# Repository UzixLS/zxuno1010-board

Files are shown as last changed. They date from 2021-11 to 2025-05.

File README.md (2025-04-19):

## ZX-UNO.1010
10x10cm PCB variant of ZX-Uno project

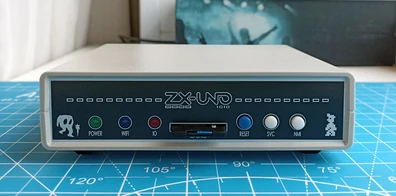
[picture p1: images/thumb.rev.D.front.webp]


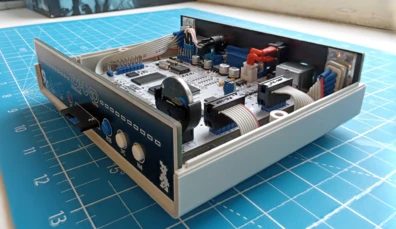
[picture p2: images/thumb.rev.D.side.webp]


[[More photos]](images/README.md)

Tech specs:
- Fully compatible with ZX Uno v4.1 and ZX-Uno VGA 2M
- XC6SLX9 FPGA
- 2Mb SRAM memory
- VGA video output
- PAL/NTSC video + audio output via 3.5 jack connector (raspberry-pi compatible pinout)
- PS/2 keyboard and mouse ports
- 2xDB-9 ports for Atari-compatible joysticks
- SD/microSD card slot
- Tape input via Bluetooth module or ordinary 3.5 jack
- MIDI
- WiFi module
- RTC (starting from rev.B)
- Type C (starting from rev.D) or MicroUSB power supply
- Board optimized for G738 and G706 cases

FAQ on official site: [link](https://uto.speccy.org/zxunofaq_en.html)

Some random photos: [link](https://cloud.err200.net/index.php/s/73TR85tYZkMm8Ax?path=%2Fzxuno1010)

### Changelog
* Rev.A - first release ([main pcb errata](pcb/rev.A/ERRATA.txt) and [covers errata](pcb_covers/rev.A/ERRATA.txt)).
* Rev.A1 - fixes all known issues of rev.A.
* Rev.B:
    * added RTC
    * changed second joystick port wiring - in rev.A it's has been wired like in ZXUNO-VGA2M, but now it's wired like Joysplitter, which is officially supported way
    * joysticks are now powered by +5V rail instead of +3.3V - this should improve compatibility with various RF gamepads
    * optimized SAM2695 footprint for hand soldering
    * added opamp for proper MIDI sound mixing
    * added buffer in DAC circuit
    * added separate LDO for SD card and WiFi module
    * added resistor between WiFi's GPIO15 and GND to prevent IC heating
    * remove beeper (which wasn't used anyway)
    * improved power distribution for FPGA chip
    * pcb corners are rounded now
    * experimental tape-in circuit
* Rev.C:
    * added dedicated LDO for audio to improve noise floor
    * added optional capacitor for NTSC quartz stability
    * added missing decoupling capacitor on RTC power rail
    * added current-limiting resistors after opamp on sound output
    * changed R76, R80 from 10kΩ to 8.2kΩ
    * changed U10 opamp from NE5532 to LMV358 as it better suited for low-voltage operation
    * 3mm front leds replaced by 5mm
    * experimental reset circuit based on MAX809
    * reverted to old tape-in circuit
* Rev.D:
    * used USB Type C instead of Micro USB
    * PJ-320 3.5mm jack replaced by PJ-322
    * added solder jumper to select 3.5mm jack CVBS pinout
    * MIDI synthesizer U6 uses clean analog power rail now
    * improved W25Q128 footprint to able to install IC in WSON package
    * some minor PCB layout changes to reduce WiFi interference
    * reverted to old reset circuit
* Rev.D1:
    * changed R16 from 220Ω to 1kΩ to reduce power led bightness
    * changed R70, R71 from 10kΩ to 12kΩ to improve balance with AY
    * changed C51 from 100nF to 1uF to improve audio noise floor
    * changed C13 value as some quartz failed to start with 4.3pF load
    * changed U17 from LP2985-3.3 to TPS7A2033PDBVR due to better PSRR
    * changed U15 from 74LVC2G34 to 74LVC2G04 as it's more common in my projects

### References
* ZX Uno official site: [link](https://zxuno.speccy.org/index_e.shtml)
* ZX Uno VGA 2M: [link](https://github.com/ManuFerHi/ZXUNO_VGA_2M)
* Great collection of cores, games and much stuff for ZX Uno: [link](https://www.zxuno.com/forum/viewtopic.php?f=27&t=4142), [in english](https://www-zxuno-com.translate.goog/forum/viewtopic.php?f=27&t=4142&_x_tr_sl=es&_x_tr_tl=en)

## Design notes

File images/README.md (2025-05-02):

# Gallery

## Revision D

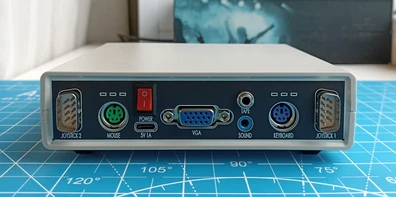
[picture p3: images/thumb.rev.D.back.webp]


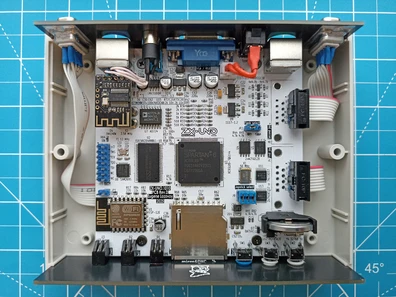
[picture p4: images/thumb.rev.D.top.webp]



## Revision C
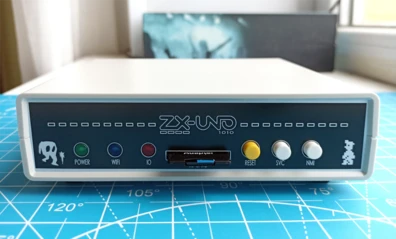
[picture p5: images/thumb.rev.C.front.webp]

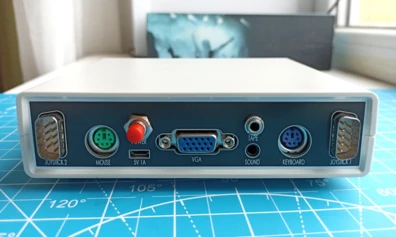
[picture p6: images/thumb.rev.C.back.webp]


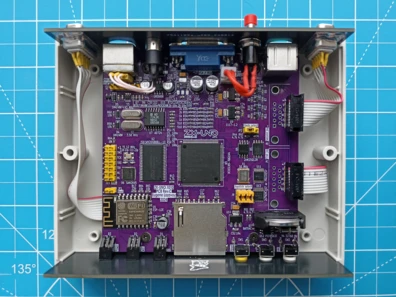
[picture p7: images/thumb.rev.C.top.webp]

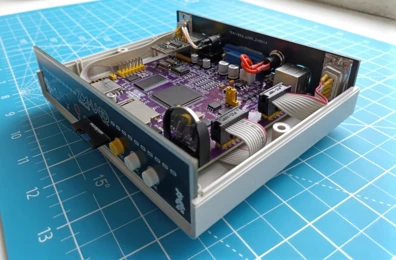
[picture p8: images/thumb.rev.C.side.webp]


## Revision A
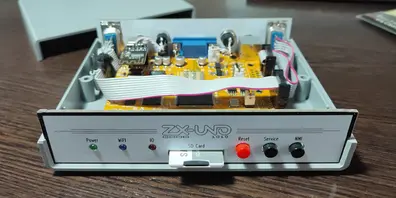
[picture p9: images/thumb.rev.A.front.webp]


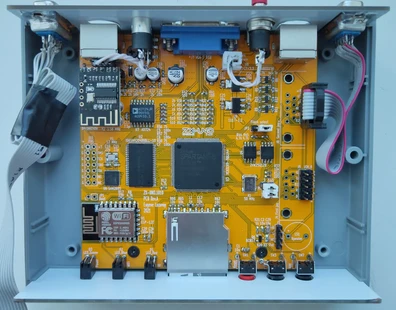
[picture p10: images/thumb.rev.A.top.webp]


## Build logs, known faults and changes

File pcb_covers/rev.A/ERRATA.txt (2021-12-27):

1. All holes should be 0.5mm lower;
2. PS/2 holes should have 6.3mm radius.

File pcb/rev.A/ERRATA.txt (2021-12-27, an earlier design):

1. R8 = 0 ohm;
2. C13 = 4.3pF;
3. D1 led behaviour is inverted (led off when SD is active).

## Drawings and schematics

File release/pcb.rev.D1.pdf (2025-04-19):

1 | 2 | 3 | 4 | 5 | 6 | 7 | 8 | 9 | 10

A

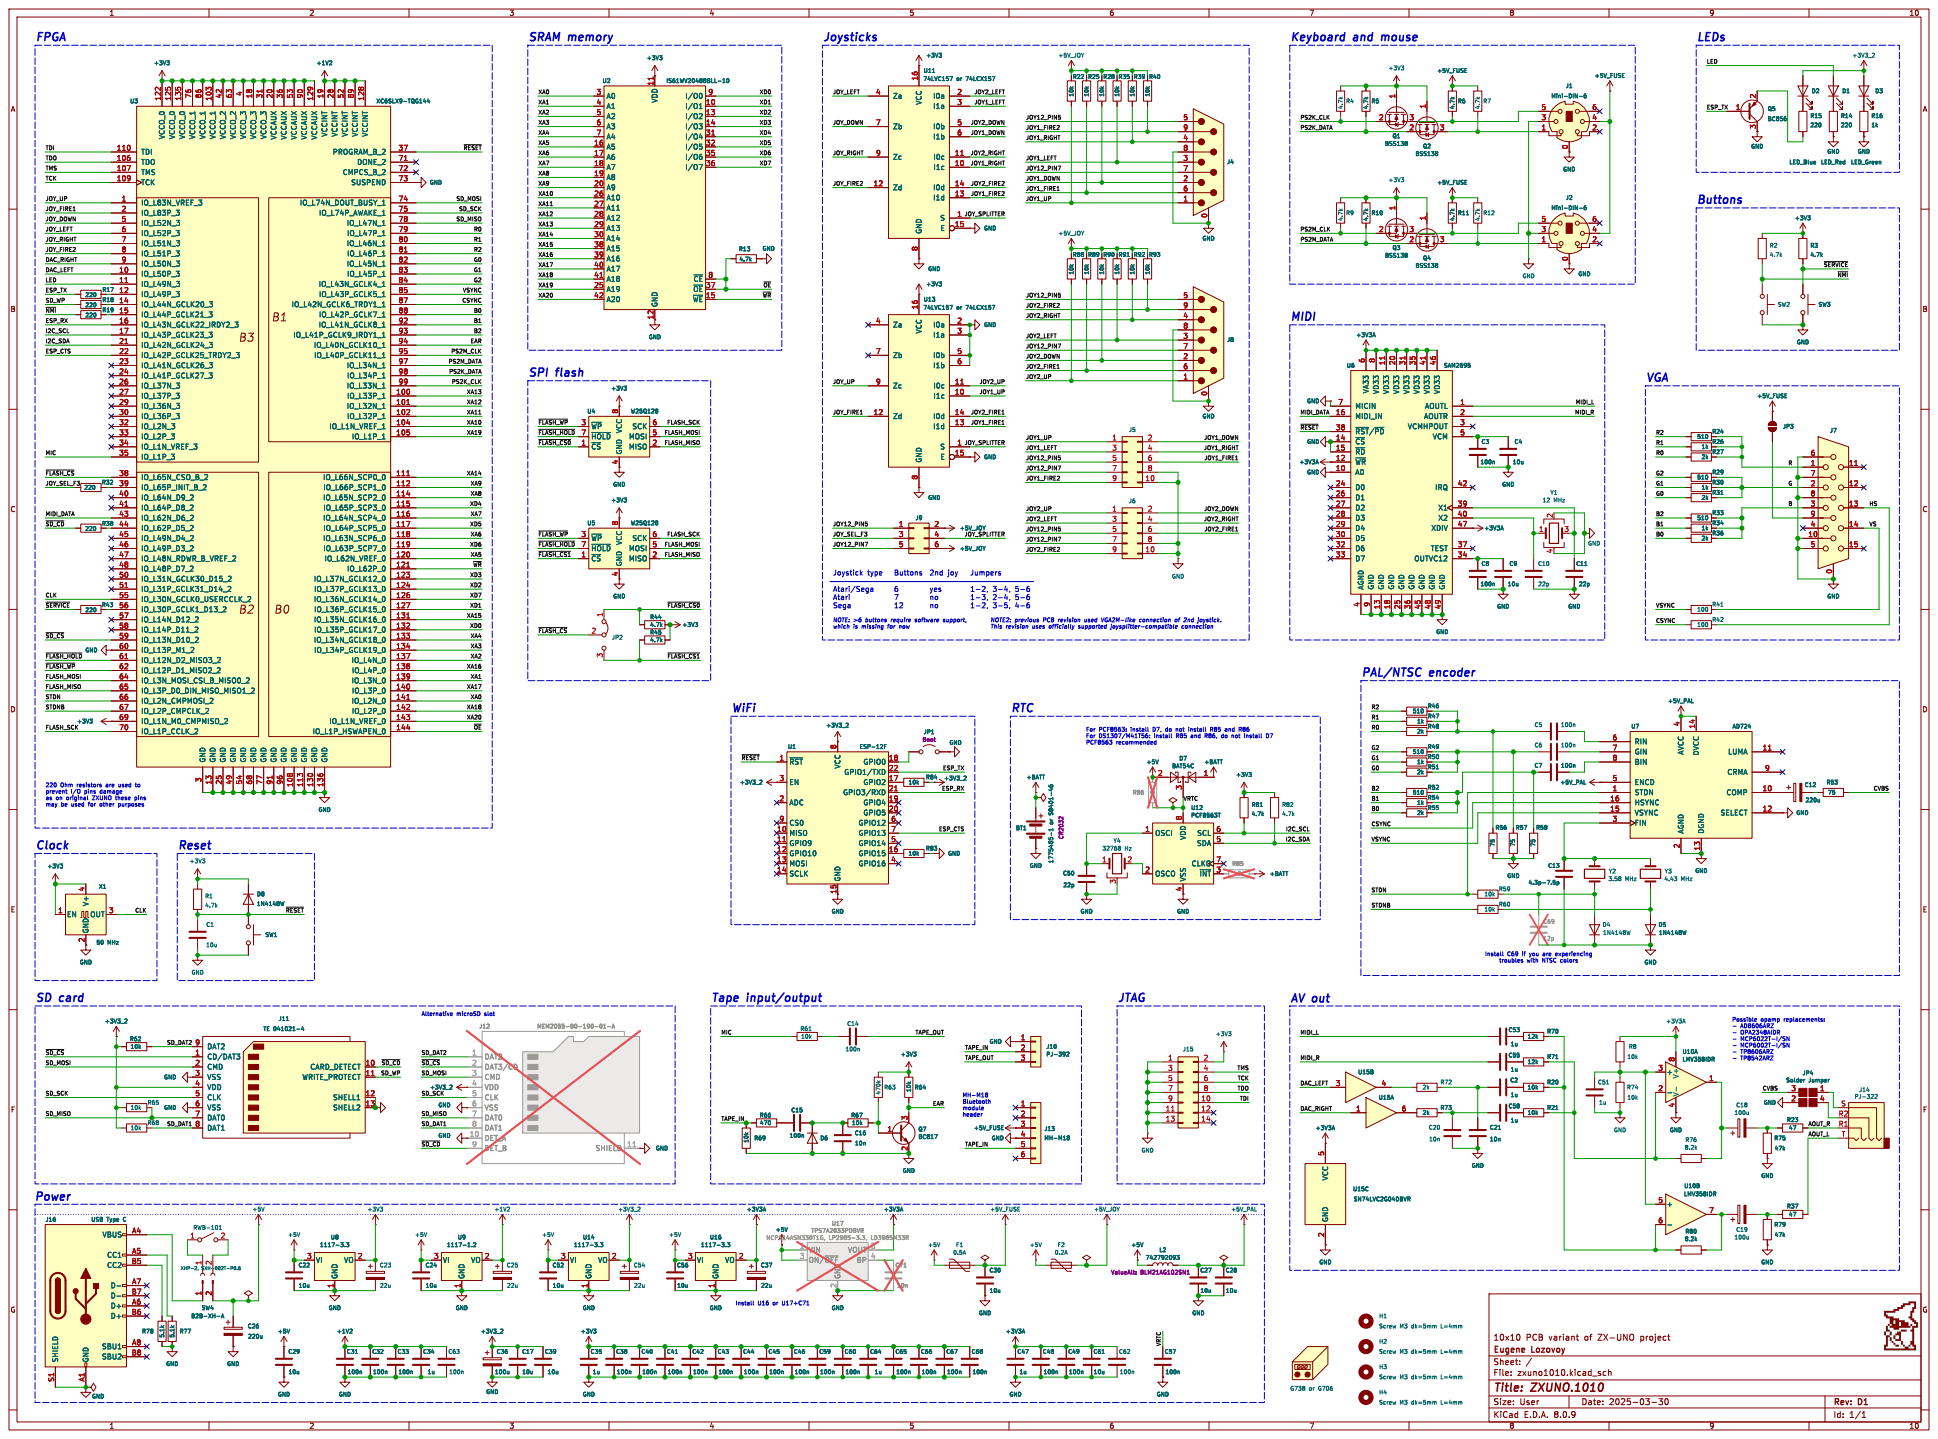
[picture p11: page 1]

4 MOSI 5 SCK 6 ~{HOLD} 7 VCC

Joystick type Atari/Sega Atari Sega

PAL/NTSC encoder MH-M18 Bluetooth module
B1G2 G1 R0 DAC_LEFT DAC_RIGHT MIDI_R

12 DGND 13 DVCC ¹⁴ VSYNC

4 SDA 5 SCL 6 CLKO 7 VDD

2 ON/~{OFF} 3 BP 4 VOUT 5 U17 TPS7A2033PDBVR

2 ON/~{OFF} 3 BP 4 VOUT 5 C65

1 | 2 | 3 | 4 | 5 | 6

A

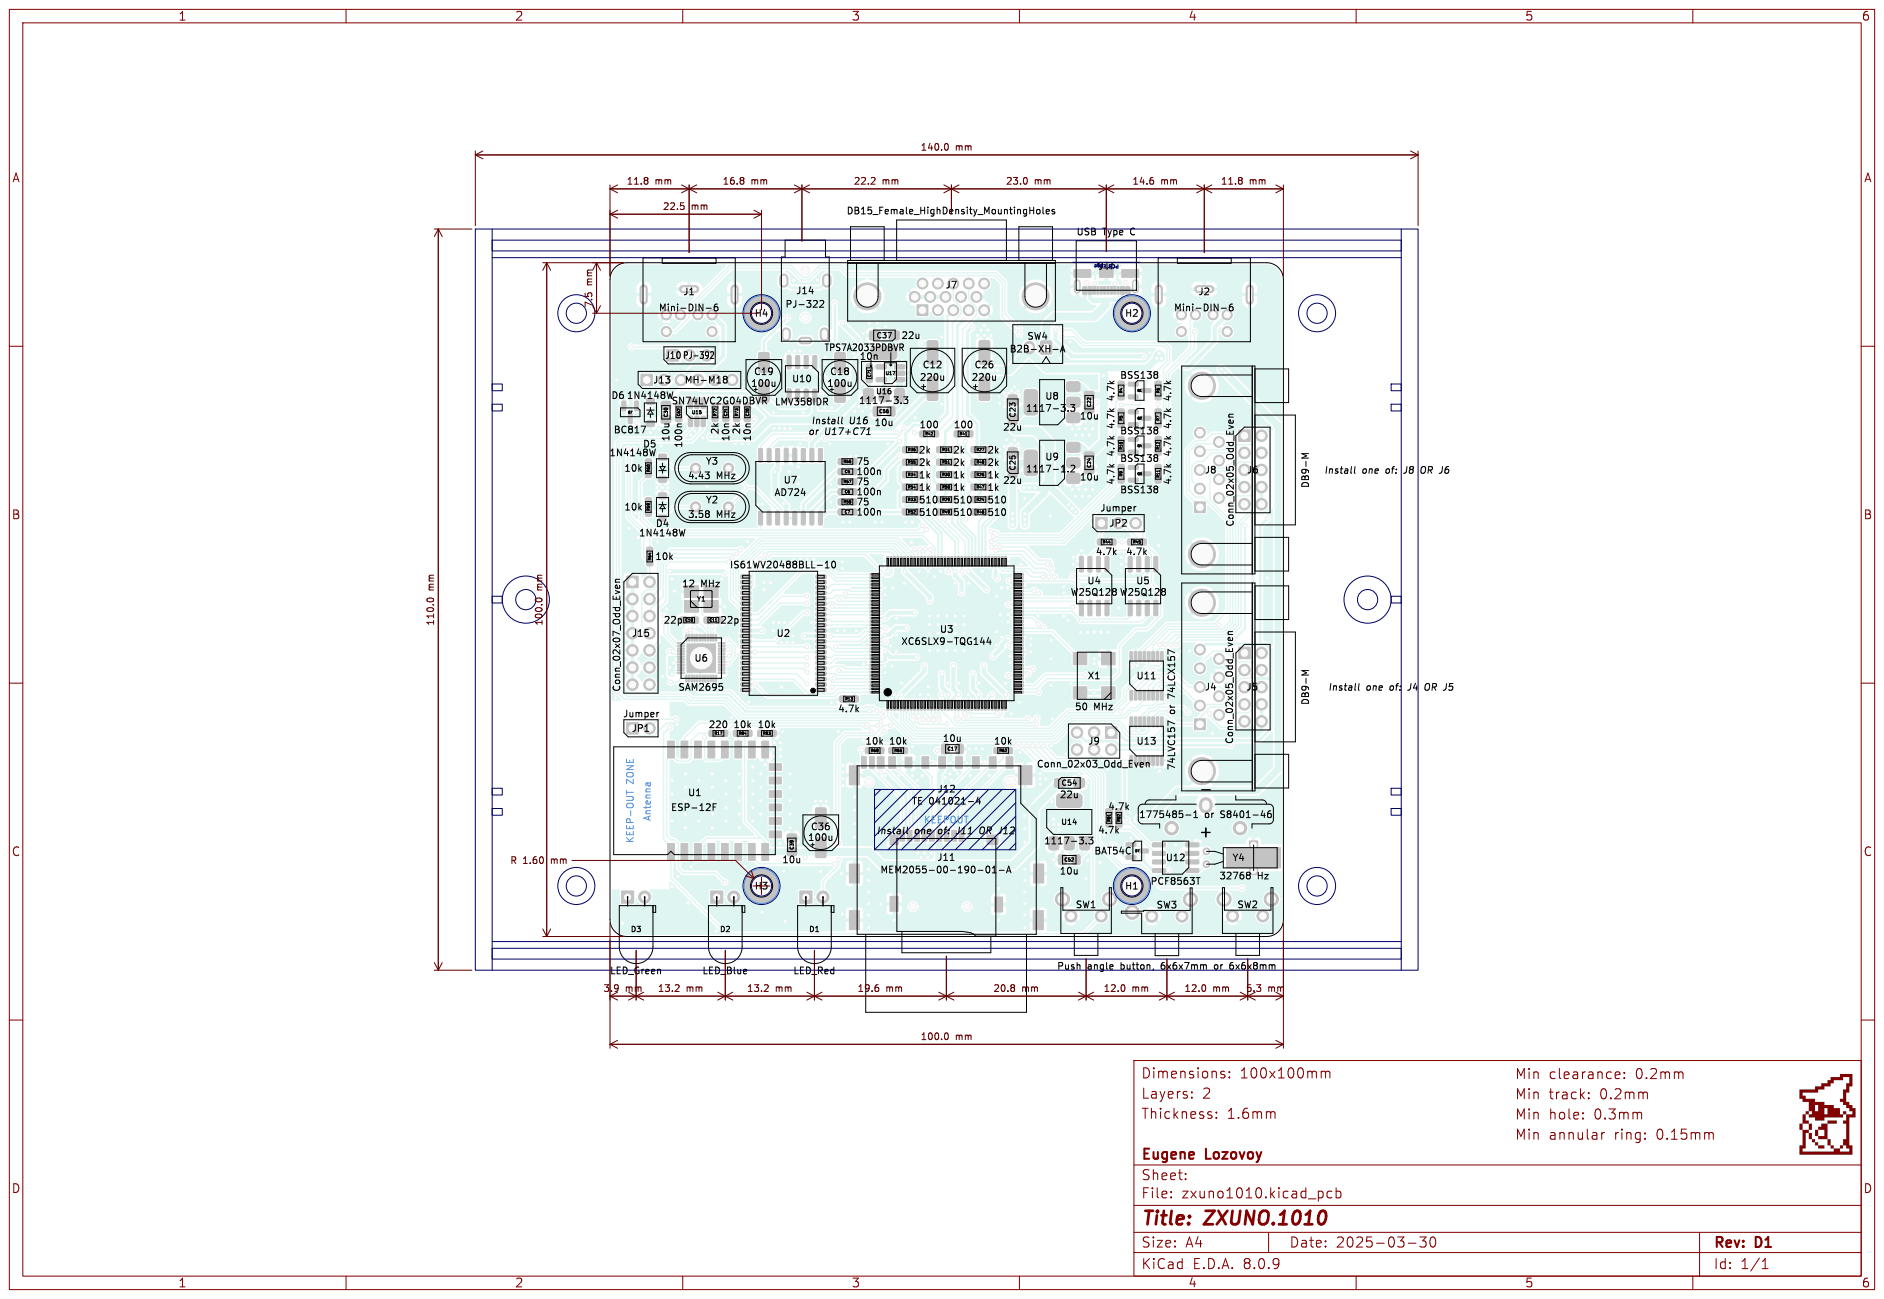
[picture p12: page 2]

1 | 2 | 3 | 4 | 5 | 6

A

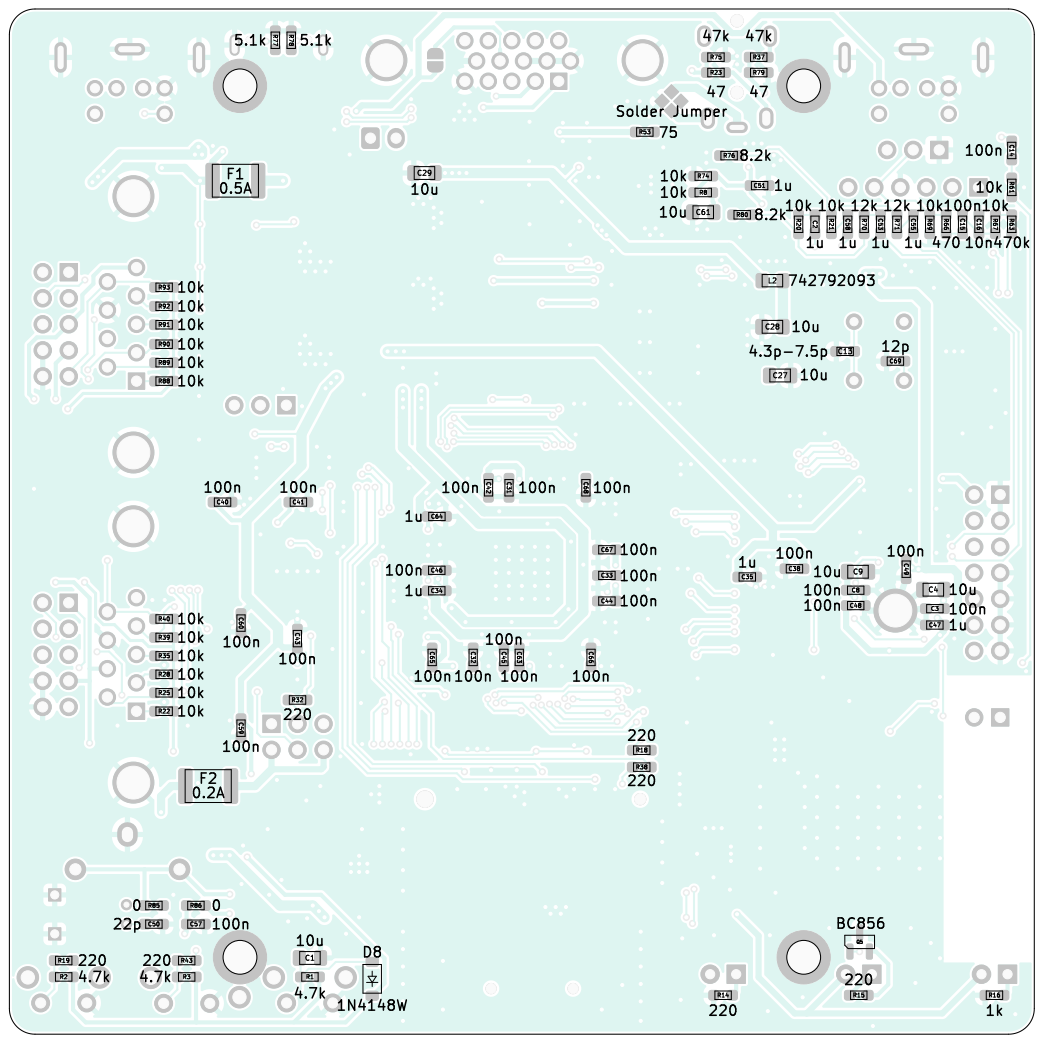
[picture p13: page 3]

# Bill Of Materials

References | | | Value | Footprint | Qty
BT1 | 1775485-1 or S8401-46 | my:CR2032V | 1
C1 C4 C9 C17 C22 C24 C27 C28 C29 C30 C39 C52 C56 C61 | 10u | Capacitor_SMD:C_0805_2012Metric_Pad1.1 8x1.45mm_HandSolder | 14
C2 C34 C35 C47 C51 C53 C55 C58 C64 | 1u | Capacitor_SMD:C_0603_1608Metric_Pad1.0 8x0.95mm_HandSolder | 9
C3 C5 C6 C7 C8 C14 C15 C31 C32 C33 C38 C40 C41 C42 C43 C44 C45 C46 C48 C49 C57 C59 C60 C62 C63 C65 C66 C67 C68 | 100n | Capacitor_SMD:C_0603_1608Metric_Pad1.0 8x0.95mm_HandSolder | 29
C10 C11 C50 | 22p | Capacitor_SMD:C_0603_1608Metric_Pad1.0 8x0.95mm_HandSolder | 3
C12 C26 | 220u | Capacitor_SMD:CP_Elec_6.3x7.7 | 2
C13 | 4.3p-7.5p | Capacitor_SMD:C_0603_1608Metric_Pad1.0 8x0.95mm_HandSolder | 1
C16 C20 C21 | 10n | Capacitor_SMD:C_0603_1608Metric_Pad1.0 8x0.95mm_HandSolder | 3
C18 C19 C36 | 100u | Capacitor_SMD:CP_Elec_5x5.9 | 3
C23 C25 C37 C54 | 22u | Capacitor_Tantalum_SMD:CP_EIA-3216-18_ Kemet-A_Pad1.58x1.35mm_HandSolder | 4
D1 | LED_Red | LED_THT:LED_D5.0mm_Horizontal_O1.27m m_Z3.0mm | 1
D2 | LED_Blue | LED_THT:LED_D5.0mm_Horizontal_O1.27m m_Z3.0mm | 1
D3 | LED_Green | LED_THT:LED_D5.0mm_Horizontal_O1.27m m_Z3.0mm | 1
D4 D5 D6 D8 | 1N4148W | Diode_SMD:D_SOD-123 | 4
D7 | BAT54C | Package_TO_SOT_SMD:SOT-23 | 1
F1 | 0.5A | Fuse:Fuse_1812_4532Metric_Pad1.30x3.40 mm_HandSolder | 1
F2 | 0.2A | Fuse:Fuse_1812_4532Metric_Pad1.30x3.40 mm_HandSolder | 1
H1 H2 H3 H4 | Screw M3 dk=5mm L=4mm | my:MountingHole_3.2mm_M3_dk5.2mm_Ma sk | 4
J1 J2 | Mini-DIN-6 | my:minidin-6 | 2
J3 | XHP-2, SXH-002T-P0.6 | | 1
J5 J6 | Conn_02x05_Odd_Even | Connector_PinHeader_2.54mm:PinHeader_2 x05_P2.54mm_Vertical | 2
J7 | DB15_Female_HighDensity_Mounti ngHoles | Connector_Dsub:DSUB-15-HD_Female_Hori zontal_P2.29x1.98mm_EdgePinOffset3.03m m_Housed_MountingHolesOffset4.94mm | 1
J9 | Conn_02x03_Odd_Even | Connector_PinHeader_2.54mm:PinHeader_2 x03_P2.54mm_Vertical | 1
J10 | PJ-392 | Connector_PinHeader_2.54mm:PinHeader_1 x03_P2.54mm_Vertical | 1
J11 | TE 041021-4 | my:SD_TE_2041021-mod | 1
J12 | MEM2055-00-190-01-A | my:GCT-MEM2055-00-190-01-A | 1

# zxuno1010 rev.D1 BOM page 1/3
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

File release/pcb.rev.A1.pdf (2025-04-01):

1 | 2 | 3 | 4 | 5 | 6 | 7 | 8 | 9

A

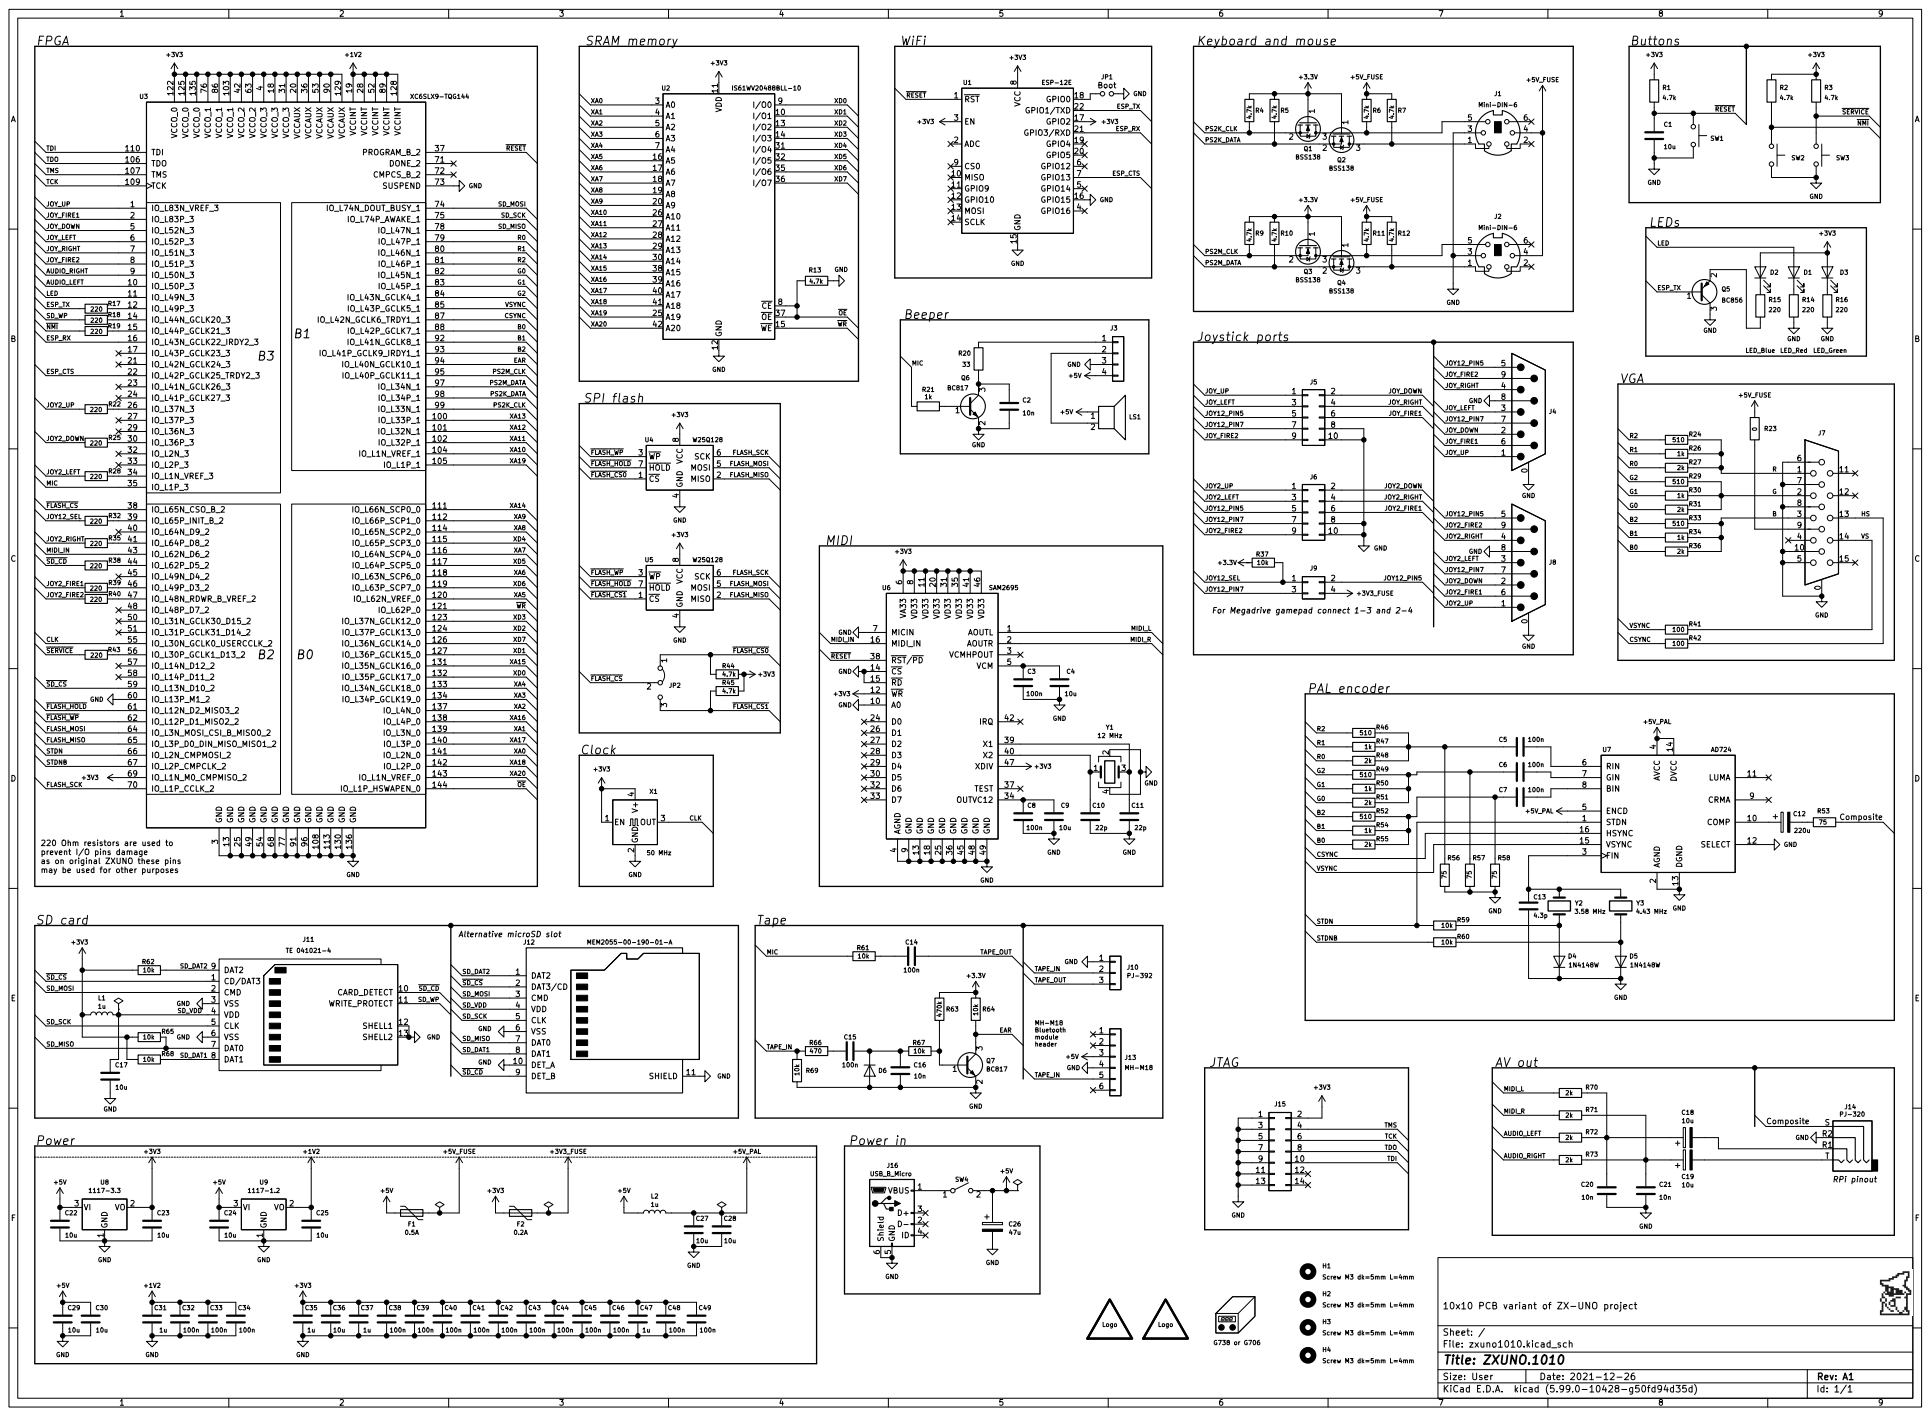
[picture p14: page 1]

For Megadrive gamepad connect 1-3 and 2-4

220 Ohm resistors are used to
prevent I/O pins damage
as on original ZXUNO these pins
may be used for other purposes

10x10 PCB variant of ZX-UNO project

1

2

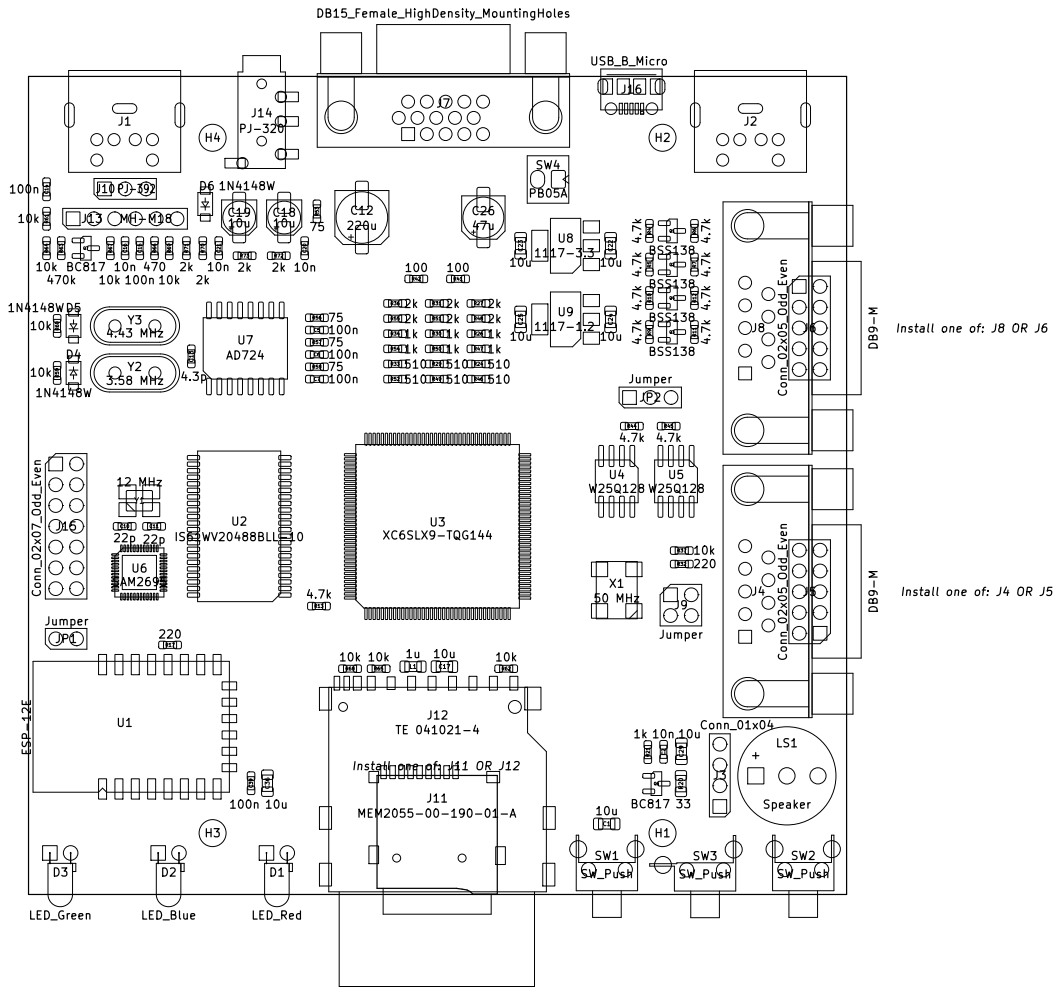
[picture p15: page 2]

Install one of: J8 OR J6

Install one of: J4 OR J5

1 | 2 | 3 | 4 | 5 | 6

A

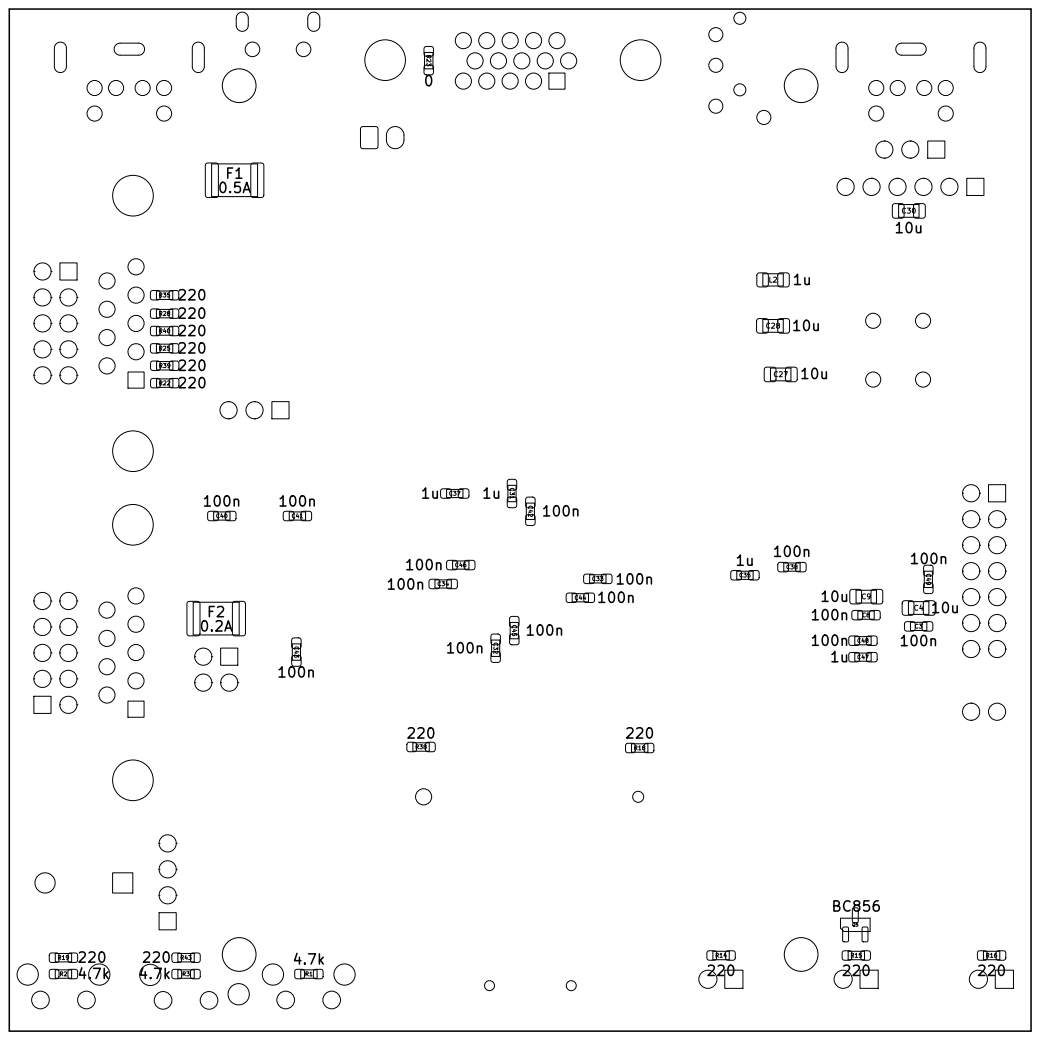
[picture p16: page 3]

1 | 2 | 3 | 4 | 5 | 6

A

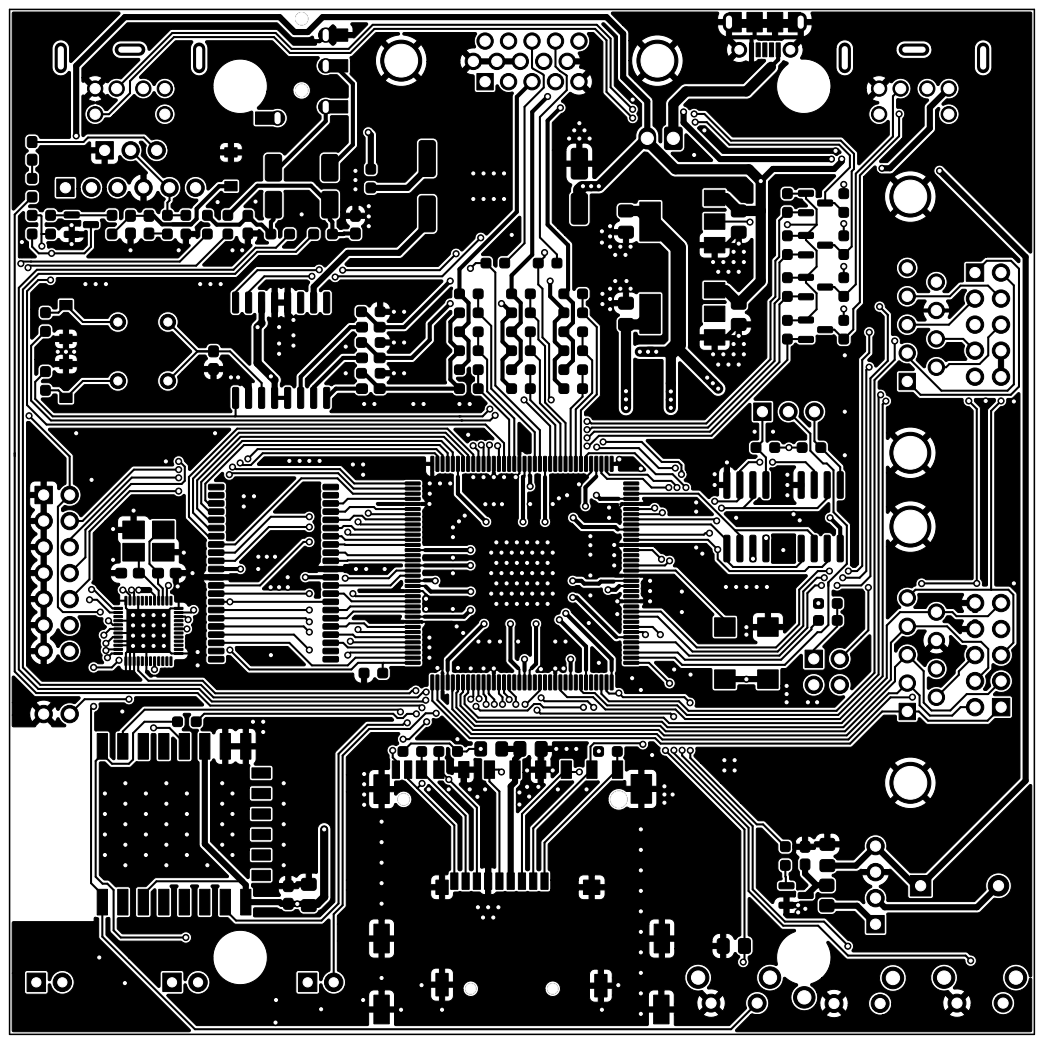
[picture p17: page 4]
Title:; File: zxuno1010.kicad_pcb; Sheet:

1 | 2 | 3 | 4 | 5 | 6

A

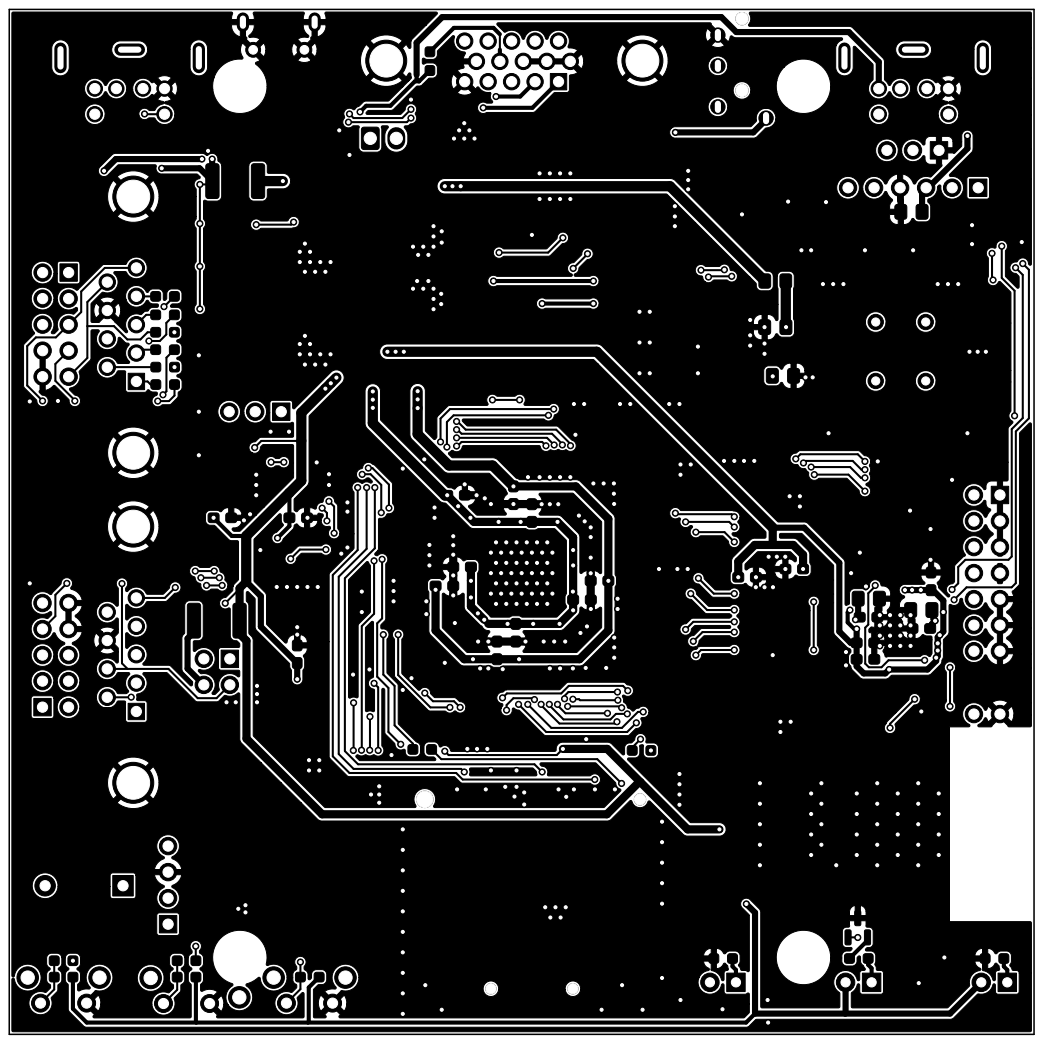
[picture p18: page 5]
Title:; File: zxuno1010.kicad_pcb; Sheet:

Designator | Package | Designation | Quantity
C11,C10 | C_0603_1608Metric_Pad1.08x0.95mm_HandSolder | 22p | 2
C12 | CP_Elec_6.3x7.7 | 220u | 1
C13 | C_0603_1608Metric_Pad1.08x0.95mm_HandSolder | 4.3p | 1
C15,C14,C39,C6,C5,C7,C3,C38,C 32,C42,C34,C40,C33,C48,C44,C8 ,C45,C41,C46,C43,C49 | C_0603_1608Metric_Pad1.08x0.95mm_HandSolder | 100n | 21
C18,C19 | CP_Elec_4x5.4 | 10u | 2
C20,C16,C2,C21 | C_0603_1608Metric_Pad1.08x0.95mm_HandSolder | 10n | 4
C25,C29,C1,C17,C36,C23,C22,C2 4,C30,C9,C28,C27,C4 | C_0805_2012Metric_Pad1.18x1.45mm_HandSolder | 10u | 13
C26 | CP_Elec_5x5.9 | 47u | 1
C35,C31,C47,C37 | C_0603_1608Metric_Pad1.08x0.95mm_HandSolder | 1u | 4
D1 | LED_D3.0mm_Horizontal_O1.27mm_Z6.0mm | LED_Red | 1
D2 | LED_D3.0mm_Horizontal_O1.27mm_Z6.0mm | LED_Blue | 1
D3 | LED_D3.0mm_Horizontal_O1.27mm_Z6.0mm | LED_Green | 1
D4,D6,D5 | D_SOD-123 | 1N4148W | 3
F1 | Fuse_1812_4532Metric_Pad1.30x3.40mm_HandSolder | 0.5A | 1
F2 | Fuse_1812_4532Metric_Pad1.30x3.40mm_HandSolder | 0.2A | 1
H1,H2,H3,H4 | MountingHole_3.2mm_M3_dk5.2mm_Mask | Screw M3 dk=5mm L=4mm | 4
J10 | PinHeader_1x03_P2.54mm_Vertical | PJ-392 | 1
J11 | SD_TE_2041021-mod | TE 041021-4 | 1
J12 | GCT-MEM2055-00-190-01-A | MEM2055-00-190-01-A | 1
J13 | PinHeader_1x06_P2.54mm_Vertical | MH-M18 | 1
J14 | PJ-320A_D | PJ-320 | 1
J15 | PinHeader_2x07_P2.54mm_Vertical | Conn_02x07_Odd_Even | 1
J16 | USB_Micro-B_Molex-105017-0001 | USB_B_Micro | 1
J1,J2 | MINI_DIN_6_33PRIMARY | Mini-DIN-6 | 2
J3 | PinHeader_1x04_P2.54mm_Vertical | Conn_01x04 | 1
J5,J6 | PinHeader_2x05_P2.54mm_Vertical | Conn_02x05_Odd_Even | 2
J7 | DSUB-15-HD_Female_Horizontal_P2.29x1.98mm_EdgePinOffset3.03mm_House d_MountingHolesOffset4.94mm | DB15_Female_HighDensi ty_MountingHoles | 1
J8,J4 | DSUB-9_Male_Horizontal_P2.77x2.84mm_EdgePinOffset4.94mm_Housed_ MountingHolesOffset7.48mm | DB9-M | 2
J9 | PinHeader_2x02_P2.54mm_Vertical | Jumper | 1
JP1 | PinHeader_1x02_P2.54mm_Vertical | Jumper | 1
JP2 | PinHeader_1x03_P2.54mm_Vertical | Jumper | 1
L1,L2 | L_0805_2012Metric_Pad1.15x1.40mm_HandSolder | 1u | 2
LS1 | Buzzer_12x9.5RM7.6 | Speaker | 1
Q3,Q1,Q4,Q2 | SOT-23 | BSS138 | 4
Q5 | SOT-23 | BC856 | 1
Q6,Q7 | SOT-23 | BC817 | 2
R20 | R_0805_2012Metric_Pad1.20x1.40mm_HandSolder | 33 | 1
R23 | R_0603_1608Metric_Pad0.98x0.95mm_HandSolder | 0 | 1
R26,R21,R54,R34,R50,R30,R47 | R_0603_1608Metric_Pad0.98x0.95mm_HandSolder | 1k | 7
R32,R17,R25,R38,R14,R35,R15, R40,R16,R39,R28,R22,R43,R18, | R_0603_1608Metric_Pad0.98x0.95mm_HandSolder | 220 | 15
R36,R73,R70,R31,R51,R71,R55, R72,R48,R27 | R_0603_1608Metric_Pad0.98x0.95mm_HandSolder | 2k | 10
R42,R41 | R_0603_1608Metric_Pad0.98x0.95mm_HandSolder | 100 | 2
R49,R24,R29,R52,R33,R46 | R_0603_1608Metric_Pad0.98x0.95mm_HandSolder | 510 | 6
R57,R56,R58,R53 | R_0603_1608Metric_Pad0.98x0.95mm_HandSolder | 75 | 4
R63 | R_0603_1608Metric_Pad0.98x0.95mm_HandSolder | 470k | 1
R64,R67,R68,R37,R59,R69,R65, R60,R62,R61 | R_0603_1608Metric_Pad0.98x0.95mm_HandSolder | 10k | 10
R66 | R_0603_1608Metric_Pad0.98x0.95mm_HandSolder | 470 | 1
R7,R9,R13,R10,R45,R5,R4,R12,R 11,R44,R6,R1,R3,R2 | R_0603_1608Metric_Pad0.98x0.95mm_HandSolder | 4.7k | 14
SW3,SW1,SW2 | SW_Tactile_SPST_Angled_PTS645Vx58-2LFS | SW_Push | 3
SW4 | Molex_KK-254_AE-6410-02A_1x02_P2.54mm_Vertical | PB05A | 1
U1 | ESP-12E | ESP-12E | 1

U2 | TSOP-II-44_10.16x18.41mm_P0.8mm | IS61WV20488BLL-10 | 1
U3 | LQFP-144_20x20mm_P0.5mm | XC6SLX9-TQG144 | 1
U4,U5 | SOIC-8_5.23x5.23mm_P1.27mm-LONG | W25Q128 | 2
U6 | QFN-48-1EP_6x6mm_P0.4mm_EP4.2x4.2mm | SAM2695 | 1
U7 | SOIC-16W_7.5x10.3mm_P1.27mm | AD724 | 1
U8 | SOT-223-3_TabPin2 | 1117-3.3 | 1
U9 | SOT-223-3_TabPin2 | 1117-1.2 | 1
X1 | Oscillator_SMD_SeikoEpson_SG8002CA-4Pin_7.0x5.0mm | 50 MHz | 1
Y1 | Crystal_SMD_SeikoEpson_TSX3225-4Pin_3.2x2.5mm_HandSoldering | 12 MHz | 1
Y2 | Crystal_HC49-U_Vertical | 3.58 MHz | 1
Y3 | Crystal_HC49-U_Vertical | 4.43 MHz | 1

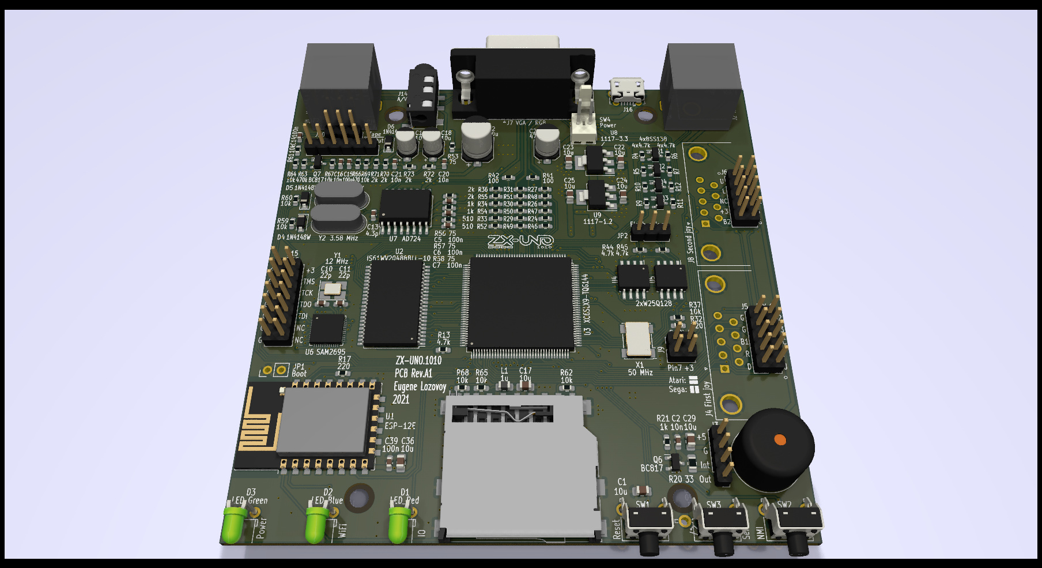
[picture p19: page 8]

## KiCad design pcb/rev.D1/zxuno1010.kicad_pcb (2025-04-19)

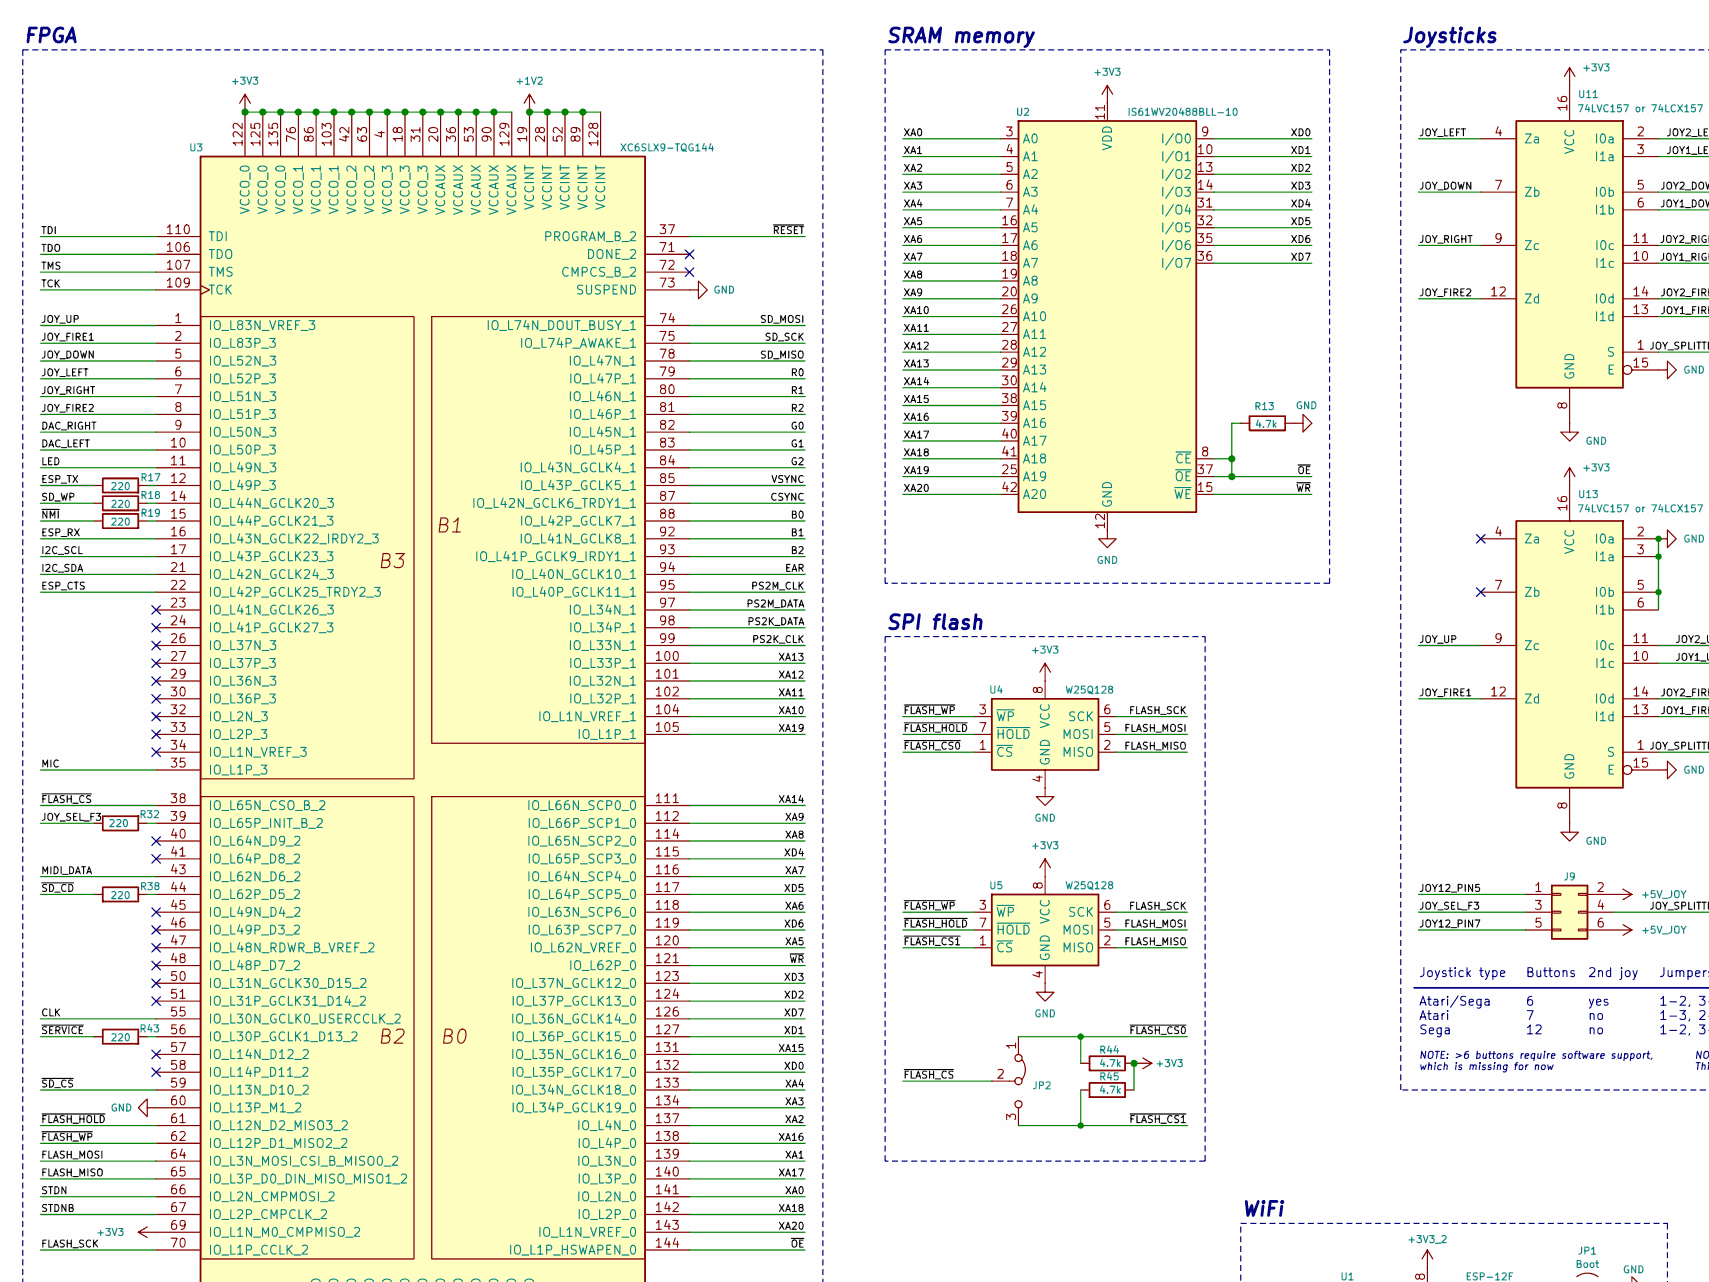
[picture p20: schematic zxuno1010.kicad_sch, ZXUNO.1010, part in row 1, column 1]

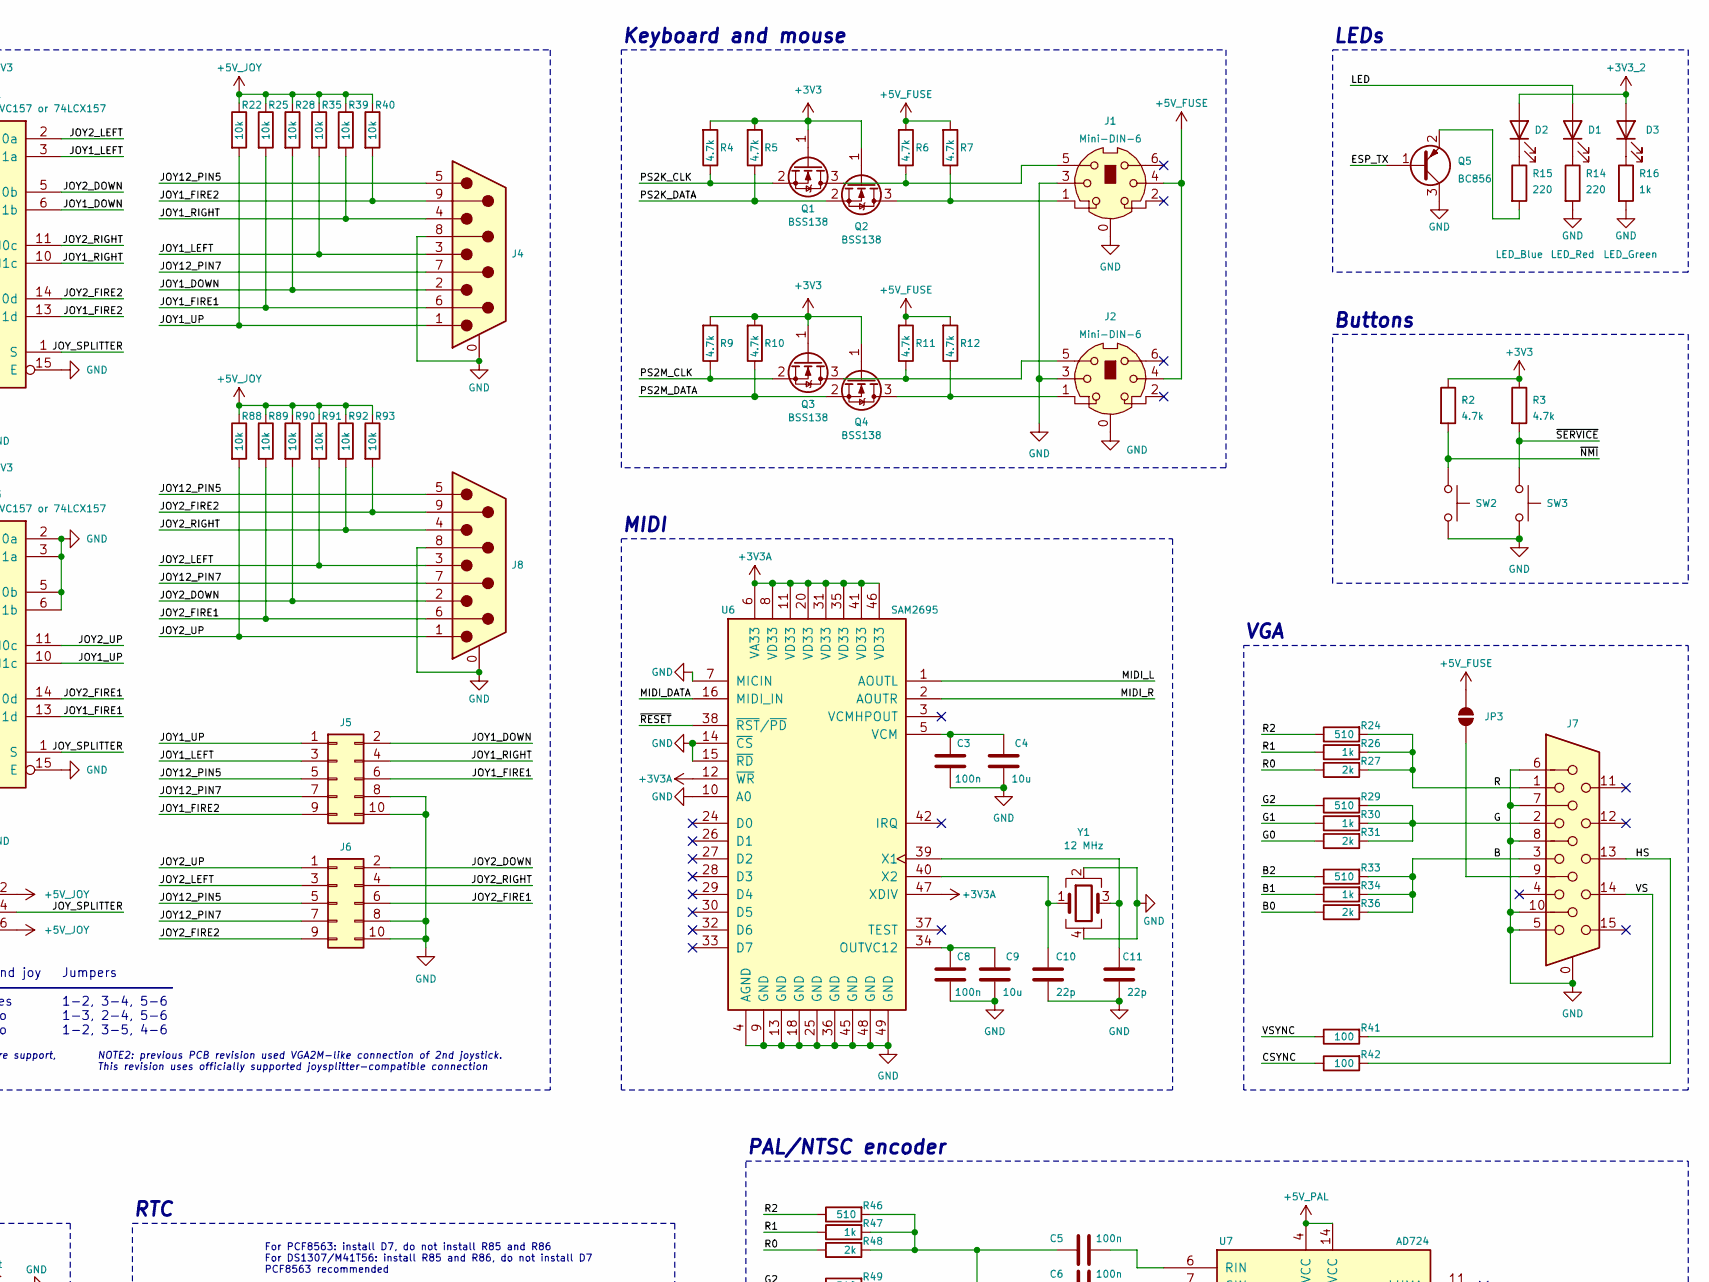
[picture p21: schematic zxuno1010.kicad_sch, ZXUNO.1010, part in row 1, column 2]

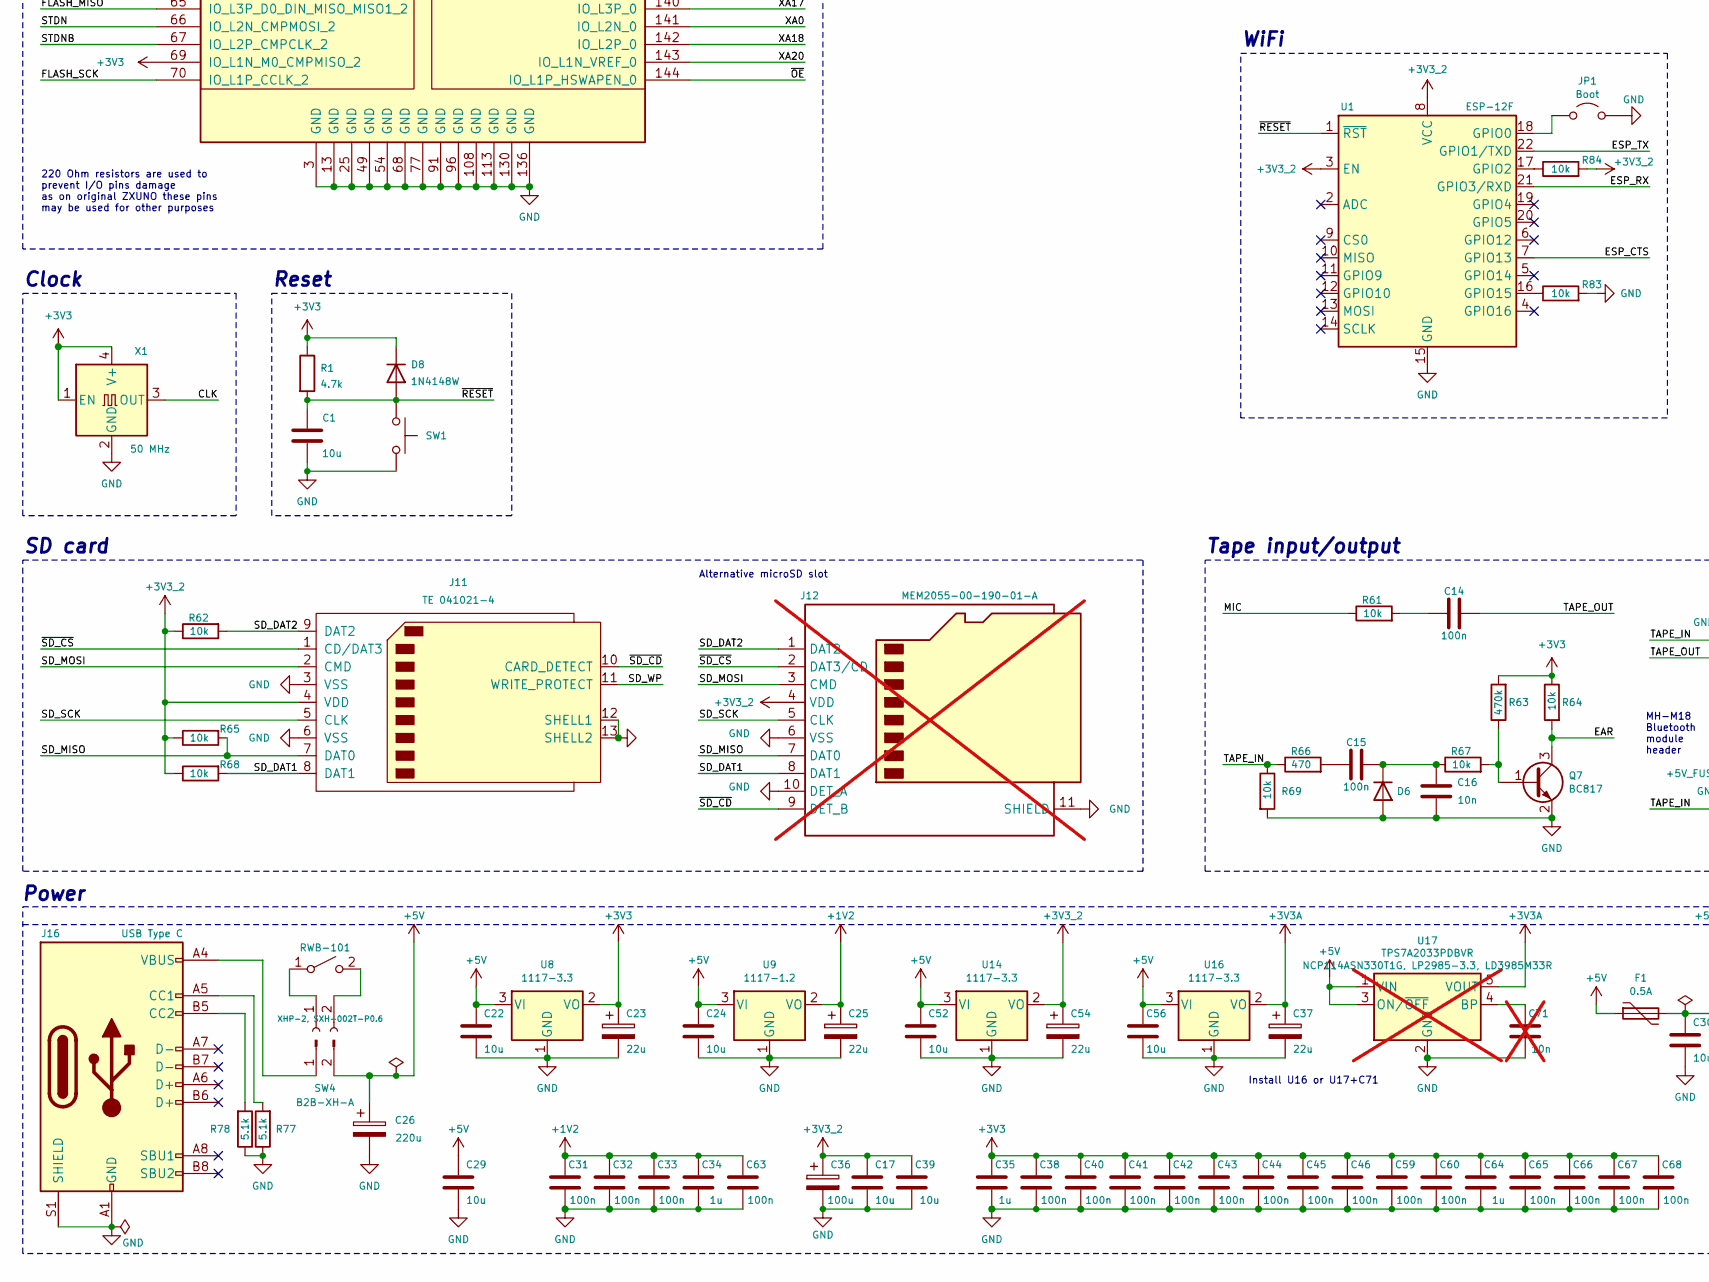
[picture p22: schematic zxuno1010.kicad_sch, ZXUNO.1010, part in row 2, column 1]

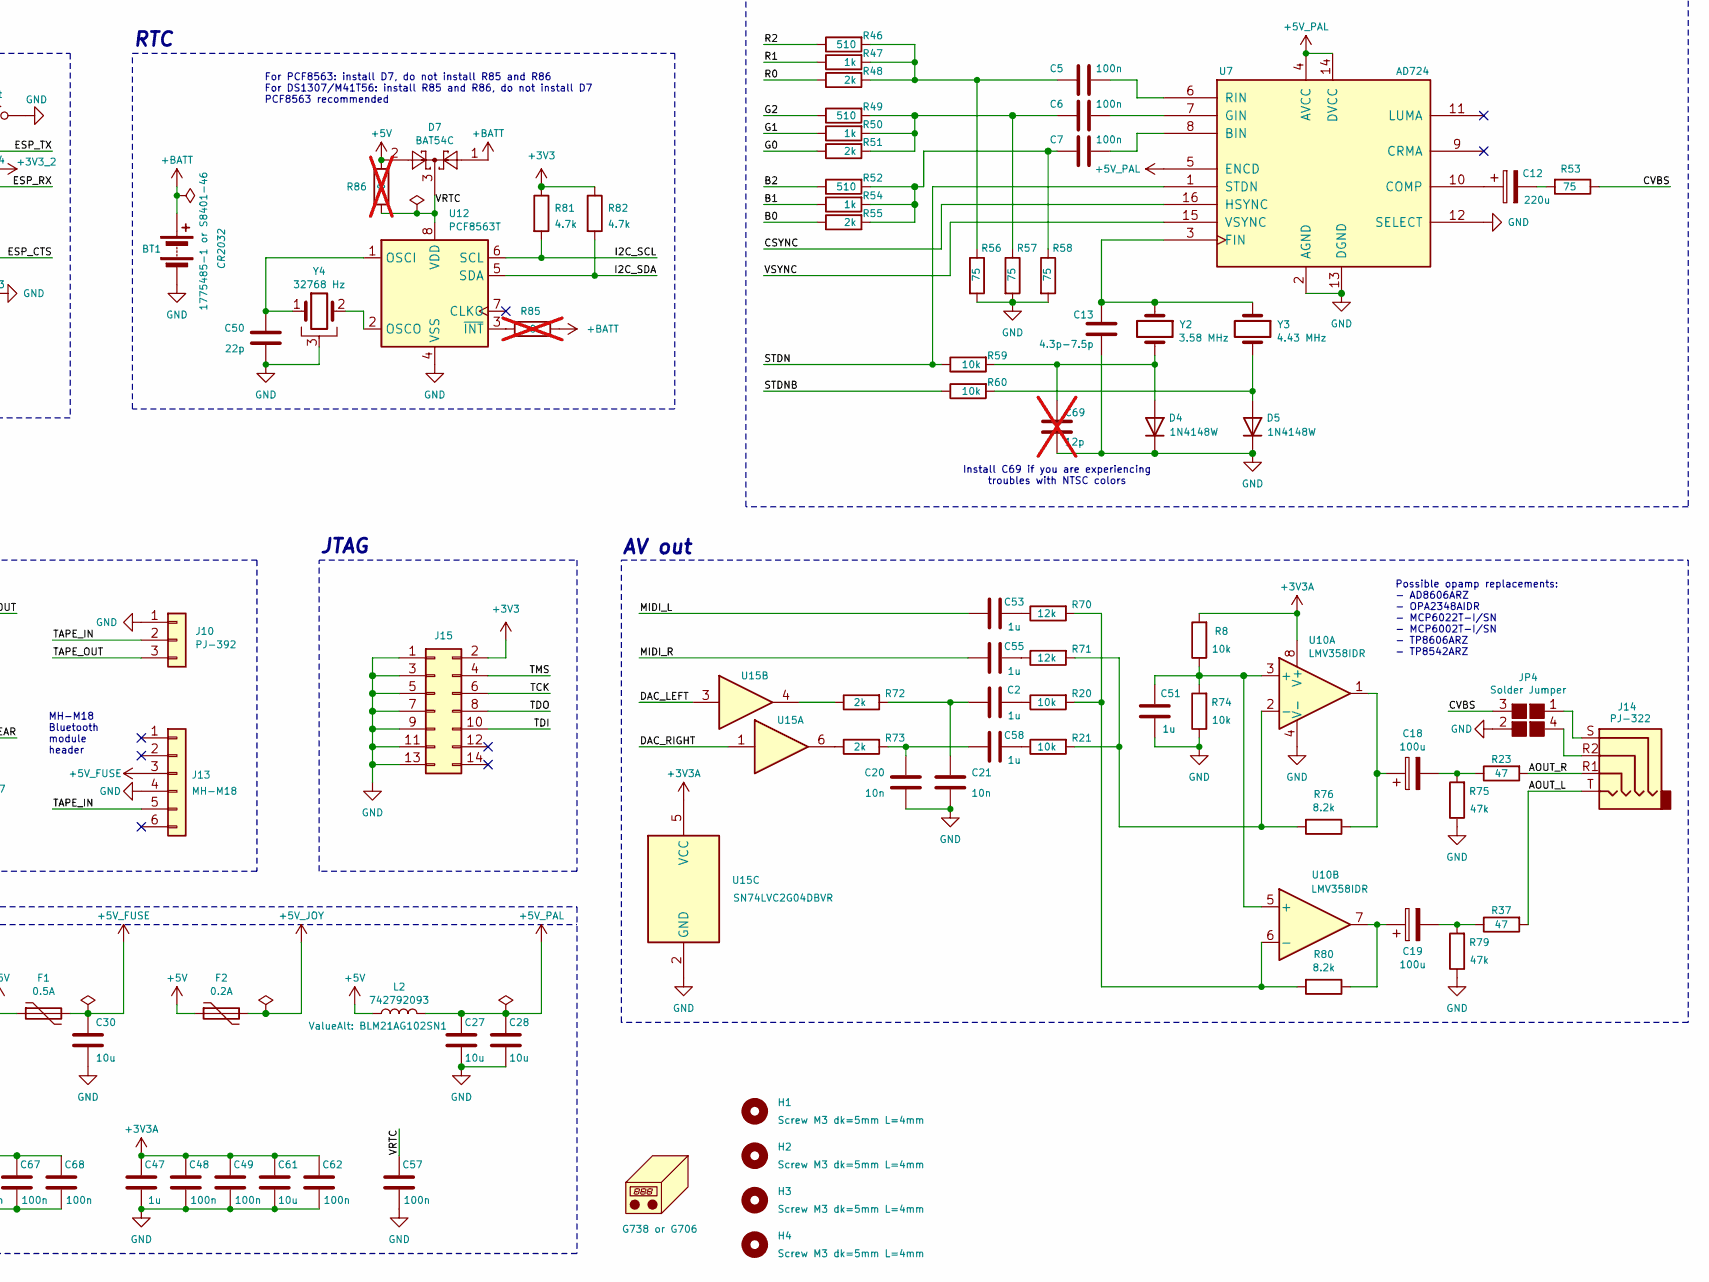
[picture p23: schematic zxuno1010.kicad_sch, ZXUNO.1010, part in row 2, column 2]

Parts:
BT1: 1775485-1 or S8401-46; CR2032V
C1, C4, C9, C17, C22, C24, C27, C28, C29, C30, C39, C52, C56, C61: 10u; C_0805_2012Metric_Pad1.18x1.45mm_HandSolder
C2, C34, C35, C47, C51, C53, C55, C58, C64: 1u; C_0603_1608Metric_Pad1.08x0.95mm_HandSolder
C3, C5, C6, C7, C8, C14, C15, C31, C32, C33, C38, C40, C41, C42, C43, C44, C45, C46, C48, C49, C57, C59, C60, C62, C63, C65, C66, C67, C68: 100n; C_0603_1608Metric_Pad1.08x0.95mm_HandSolder
C10, C11, C50: 22p; C_0603_1608Metric_Pad1.08x0.95mm_HandSolder
C12, C26: 220u; CP_Elec_6.3x7.7
C13: 4.3p-7.5p; C_0603_1608Metric_Pad1.08x0.95mm_HandSolder
C16, C20, C21: 10n; C_0603_1608Metric_Pad1.08x0.95mm_HandSolder
C18, C19, C36: 100u; CP_Elec_5x5.9
C23, C25, C37, C54: 22u; CP_EIA-3216-18_Kemet-A_Pad1.58x1.35mm_HandSolder
C69: 12p; C_0603_1608Metric_Pad1.08x0.95mm_HandSolder; not fitted
C71: 10n; C_0603_1608Metric_Pad1.08x0.95mm_HandSolder; not fitted
D1: LED_Red; LED_D5.0mm_Horizontal_O1.27mm_Z3.0mm
D2: LED_Blue; LED_D5.0mm_Horizontal_O1.27mm_Z3.0mm
D3: LED_Green; LED_D5.0mm_Horizontal_O1.27mm_Z3.0mm
D4, D5, D6, D8: 1N4148W; D_SOD-123
D7: BAT54C; SOT-23
F1: 0.5A; Fuse_1812_4532Metric_Pad1.30x3.40mm_HandSolder
F2: 0.2A; Fuse_1812_4532Metric_Pad1.30x3.40mm_HandSolder
H1, H2, H3, H4: Screw M3 dk=5mm L=4mm; MountingHole_3.2mm_M3_dk5.2mm_Mask
J1, J2: Mini-DIN-6; minidin-6
J3: XHP-2, SXH-002T-P0.6
J4, J8: DB9-M; DSUB-9_Male_Horizontal_P2.77x2.84mm_EdgePinOffset4.94mm_Hou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
J5, J6: Conn_02x05_Odd_Even; PinHeader_2x05_P2.54mm_Vertical
J7: DB15_Female_HighDensity_MountingHoles; DSUB-15-HD_Female_Horizontal_P2.29x1.98mm_EdgePinOffset3.03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
J9: Conn_02x03_Odd_Even; PinHeader_2x03_P2.54mm_Vertical
J10: PJ-392; PinHeader_1x03_P2.54mm_Vertical
J11: TE 041021-4; SD_TE_2041021-mod
J12: MEM2055-00-190-01-A; GCT-MEM2055-00-190-01-A; not fitted
J13: MH-M18; PinHeader_1x06_P2.54mm_Vertical
J14: PJ-322
J15: Conn_02x07_Odd_Even; PinHeader_2x07_P2.54mm_Vertical
J16: USB Type C; USB_C_Receptacle_HRO_TYPE-C-31-M-12_dangling
JP1: Jumper; PinHeader_1x02_P2.54mm_Vertical
JP2: Jumper; PinHeader_1x03_P2.54mm_Vertical
JP3: SolderJumper_2_Open; SolderJumper-2_P1.3mm_Open_RoundedPad1.0x1.5mm
JP4: Solder Jumper; SolderJumper-4_P1.3mm_Open
L2: 742792093; L_0805_2012Metric_Pad1.15x1.40mm_HandSolder
N1: G738 or G706; g738-g706
Q1, Q2, Q3, Q4: BSS138; SOT-23
Q5: BC856; SOT-23
Q7: BC817; SOT-23
R1, R2, R3, R4, R5, R6, R7, R9, R10, R11, R12, R13, R44, R45, R81, R82: 4.7k; R_0603_1608Metric_Pad0.98x0.95mm_HandSolder
R8, R20, R21, R22, R25, R28, R35, R39, R40, R59, R60, R61, R62, R64, R65, R67, R68, R69, R74, R83, R84, R88, R89, R90, R91, R92, R93: 10k; R_0603_1608Metric_Pad0.98x0.95mm_HandSolder
R14, R15, R17, R18, R19, R32, R38, R43: 220; R_0603_1608Metric_Pad0.98x0.95mm_HandSolder
R16, R26, R30, R34, R47, R50, R54: 1k; R_0603_1608Metric_Pad0.98x0.95mm_HandSolder
R23, R37: 47; R_0603_1608Metric_Pad0.98x0.95mm_HandSolder
R24, R29, R33, R46, R49, R52: 510; R_0603_1608Metric_Pad0.98x0.95mm_HandSolder
R27, R31, R36, R48, R51, R55, R72, R73: 2k; R_0603_1608Metric_Pad0.98x0.95mm_HandSolder
R41, R42: 100; R_0603_1608Metric_Pad0.98x0.95mm_HandSolder
R53, R56, R57, R58: 75; R_0603_1608Metric_Pad0.98x0.95mm_HandSolder
R63: 470k; R_0603_1608Metric_Pad0.98x0.95mm_HandSolder
R66: 470; R_0603_1608Metric_Pad0.98x0.95mm_HandSolder
R70, R71: 12k; R_0603_1608Metric_Pad0.98x0.95mm_HandSolder
R75, R79: 47k; R_0603_1608Metric_Pad0.98x0.95mm_HandSolder
R76, R80: 8.2k; R_0603_1608Metric_Pad0.98x0.95mm_HandSolder
R77, R78: 5.1k; R_0603_1608Metric_Pad0.98x0.95mm_HandSolder
R85, R86: 0; R_0603_1608Metric_Pad0.98x0.95mm_HandSolder; not fitted
SW1, SW2, SW3: Push angle button, 6x6x7mm or 6x6x8mm; SW_Tactile_SPST_Angled_PTS645Vx58-2LFS
SW4: B2B-XH-A; JST_XH_B2B-XH-A_1x02_P2.50mm_Vertical
SW5: RWB-101
U1: ESP-12F; ESP-12E
U2: IS61WV20488BLL-10; TSOP-II-44_10.16x18.41mm_P0.8mm
U3: XC6SLX9-TQG144; LQFP-144_20x20mm_P0.5mm
U4, U5: W25Q128; SOIC-8_5.23x5.23mm_P1.27mm-LONG
U6: SAM2695; QFN-48-1EP_6x6mm_P0.4mm_EP4.2x4.2mm
U7: AD724; SOIC-16W_7.5x10.3mm_P1.27mm
U8, U14, U16: 1117-3.3; SOT-223-3_TabPin2
U9: 1117-1.2; SOT-223-3_TabPin2
U10: LMV358IDR; SOIC-8_3.9x4.9mm_P1.27mm
U11, U13: 74LVC157 or 74LCX157; TSSOP-16_4.4x5mm_P0.65mm
U12: PCF8563T; SOIC-8_3.9x4.9mm_P1.27mm
U15: SN74LVC2G04DBVR; SOT-23-6_Handsoldering
U17: TPS7A2033PDBVR; SOT-23-5_HandSoldering; not fitted
X1: 50 MHz; Oscillator_SMD_7050_7.0x5.0mm
Y1: 12 MHz; Crystal_SMD_SeikoEpson_TSX3225-4Pin_3.2x2.5mm_HandSoldering
Y2: 3.58 MHz; Crystal_HC49-4H_Vertical
Y3: 4.43 MHz; Crystal_HC49-4H_Vertical
Y4: 32768 Hz; Crystal_C38-LF_D3.0mm_L8.0mm_Horizontal_1EP_style2

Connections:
+1V2: C25.1, C31.2, C32.2, C33.2, C34.2, C63.2, U3.19 (VCCINT), U3.28 (VCCINT), U3.52 (VCCINT), U3.89 (VCCINT), U3.128 (VCCINT), U9.2 (VO)
+3V3: C23.1, C35.2, C38.2, C40.2, C41.2, C42.2, C43.2, C44.2, C45.2, C46.2, C59.2, C60.2, C64.2, C65.2, C66.2, C67.2, C68.2, D8.1 (K), J15.2, Q1.1 (G), Q2.1 (G), Q3.1 (G), Q4.1 (G), R1.1, R2.1, R3.1, R4.2, R5.2, R9.2, R10.2, R44.1, R45.1, R63.2, R64.1, R81.1, R82.1, U2.11 (VDD), U2.33 (VDD), U3.4 (VCCO_3), U3.18 (VCCO_3), U3.20 (VCCAUX), U3.31 (VCCO_3), U3.36 (VCCAUX), U3.42 (VCCO_2), U3.53 (VCCAUX), U3.63 (VCCO_2), U3.69 (IO_L1N_M0_CMPMISO_2), U3.76 (VCCO_1), U3.86 (VCCO_1), U3.90 (VCCAUX), U3.103 (VCCO_1), U3.122 (VCCO_0), U3.125 (VCCO_0), U3.129 (VCCAUX), U3.135 (VCCO_0), U4.8 (VCC), U5.8 (VCC), U8.2 (VO), U11.16 (VCC), U13.16 (VCC), X1.1 (EN), X1.4 (V+)
+3V3A: C37.1, C47.2, C48.2, C49.2, C61.2, C62.2, R8.2, U6.6 (VA33), U6.8 (VD33), U6.11 (VD33), U6.12 (~WR), U6.20 (VD33), U6.31 (VD33), U6.35 (VD33), U6.41 (VD33), U6.46 (VD33), U6.47 (XDIV), U10.8 (V+), U15.5 (VCC), U16.2 (VO), U17.5 (VOUT)
+3V3_2: C17.2, C36.1, C39.2, C54.1, D2.2 (A), D3.2 (A), J11.4 (VDD), J12.4 (VDD), R62.1, R65.1, R68.1, R84.2, U1.3 (EN), U1.8 (VCC), U14.2 (VO)
+5V: C22.2, C24.2, C26.1, C29.2, C52.2, C56.2, D7.2, F1.1, F2.1, L2.1, R86.2, SW4.2, U8.3 (VI), U9.3 (VI), U14.3 (VI), U16.3 (VI), U17.1 (VIN), U17.3 (ON/~OFF)
+5V_FUSE: C30.2, F1.2, J1.4, J2.4, J13.3, JP3.2 (B), R6.2, R7.2, R11.2, R12.2
+5V_JOY: F2.2, J9.2, J9.6, R22.1, R25.1, R28.1, R35.1, R39.1, R40.1, R88.1, R89.1, R90.1, R91.1, R92.1, R93.1
+5V_PAL: C27.2, C28.2, L2.2, U7.4 (AVCC), U7.5 (ENCD), U7.14 (DVCC)
+BATT: BT1.1 (+), D7.1, R85.2
/AOUT_L: J14.T, R37.2
/AOUT_R: J14.R1, R23.2
/B: J7.3, R33.2, R34.2, R36.2
/B0: R36.1, R55.1, U3.88 (IO_L42P_GCLK7_1)
/B1: R34.1, R54.1, U3.92 (IO_L41N_GCLK8_1)
/B2: R33.1, R52.1, U3.93 (IO_L41P_GCLK9_IRDY1_1)
/CLK: U3.55 (IO_L30N_GCLK0_USERCCLK_2), X1.3 (OUT)
/CSYNC: R42.1, U3.87 (IO_L42N_GCLK6_TRDY1_1), U7.16 (HSYNC)
/CVBS: JP4.3, R53.1
/DAC_LEFT: U3.10 (IO_L50P_3), U15.3
/DAC_RIGHT: U3.9 (IO_L50N_3), U15.1
/EAR: Q7.3 (C), R64.2, U3.94 (IO_L40N_GCLK10_1)
/ESP_CTS: U1.7 (GPIO13), U3.22 (IO_L42P_GCLK25_TRDY2_3)
/ESP_RX: U1.21 (GPIO3/RXD), U3.16 (IO_L43N_GCLK22_IRDY2_3)
/ESP_TX: Q5.1 (B), R17.1, U1.22 (GPIO1/TXD)
/FLASH_MISO: U3.65 (IO_L3P_D0_DIN_MISO_MISO1_2), U4.2 (MISO), U5.2 (MISO)
/FLASH_MOSI: U3.64 (IO_L3N_MOSI_CSI_B_MISO0_2), U4.5 (MOSI), U5.5 (MOSI)
/FLASH_SCK: U3.70 (IO_L1P_CCLK_2), U4.6 (SCK), U5.6 (SCK)
/G: J7.2, R29.2, R30.2, R31.2
/G0: R31.1, R51.1, U3.82 (IO_L45N_1)
/G1: R30.1, R50.1, U3.83 (IO_L45P_1)
/G2: R29.1, R49.1, U3.84 (IO_L43N_GCLK4_1)
/HS: J7.13, R42.2
/I2C_SCL: R81.2, U3.17 (IO_L43P_GCLK23_3), U12.6 (SCL)
/I2C_SDA: R82.2, U3.21 (IO_L42N_GCLK24_3), U12.5 (SDA)
/JOY1_DOWN: J4.2, J5.2, R28.2, U11.6 (I1b)
/JOY1_FIRE1: J4.6, J5.6, R25.2, U13.13 (I1d)
/JOY1_FIRE2: J4.9, J5.9, R40.2, U11.13 (I1d)
/JOY1_LEFT: J4.3, J5.3, R35.2, U11.3 (I1a)
/JOY1_RIGHT: J4.4, J5.4, R39.2, U11.10 (I1c)
/JOY1_UP: J4.1, J5.1, R22.2, U13.10 (I1c)
/JOY2_DOWN: J6.2, J8.2, R90.2, U11.5 (I0b)
/JOY2_FIRE1: J6.6, J8.6, R89.2, U13.14 (I0d)
/JOY2_FIRE2: J6.9, J8.9, R93.2, U11.14 (I0d)
/JOY2_LEFT: J6.3, J8.3, R91.2, U11.2 (I0a)
/JOY2_RIGHT: J6.4, J8.4, R92.2, U11.11 (I0c)
/JOY2_UP: J6.1, J8.1, R88.2, U13.11 (I0c)
/JOY12_PIN5: J4.5, J5.5, J6.5, J8.5, J9.1
/JOY12_PIN7: J4.7, J5.7, J6.7, J8.7, J9.5
/JOY_DOWN: U3.5 (IO_L52N_3), U11.7 (Zb)
/JOY_FIRE1: U3.2 (IO_L83P_3), U13.12 (Zd)
/JOY_FIRE2: U3.8 (IO_L51P_3), U11.12 (Zd)
/JOY_LEFT: U3.6 (IO_L52P_3), U11.4 (Za)
/JOY_RIGHT: U3.7 (IO_L51N_3), U11.9 (Zc)
/JOY_SEL_F3: J9.3, R32.1
/JOY_SPLITTER: J9.4, U11.1 (S), U13.1 (S)
/JOY_UP: U3.1 (IO_L83N_VREF_3), U13.9 (Zc)
/LED: D1.2 (A), U3.11 (IO_L49N_3)
/MIC: R61.1, U3.35 (IO_L1P_3)
/MIDI_DATA: U3.43 (IO_L62N_D6_2), U6.16 (MIDI_IN)
/MIDI_L: C53.1, U6.1 (AOUTL)
/MIDI_R: C55.1, U6.2 (AOUTR)
/PS2K_CLK: Q1.2 (S), R4.1, U3.99 (IO_L33N_1)
/PS2K_DATA: Q2.2 (S), R5.1, U3.98 (IO_L34P_1)
/PS2M_CLK: Q3.2 (S), R9.1, U3.95 (IO_L40P_GCLK11_1)
/PS2M_DATA: Q4.2 (S), R10.1, U3.97 (IO_L34N_1)
/R: J7.1, R24.2, R26.2, R27.2
/R0: R27.1, R48.1, U3.79 (IO_L47P_1)
/R1: R26.1, R47.1, U3.80 (IO_L46N_1)
/R2: R24.1, R46.1, U3.81 (IO_L46P_1)
/SD_DAT1: J11.8 (DAT1), J12.8 (DAT1), R68.2
/SD_DAT2: J11.9 (DAT2), J12.1 (DAT2), R62.2
/SD_MISO: J11.7 (DAT0), J12.7 (DAT0), R65.2, U3.78 (IO_L47N_1)
/SD_MOSI: J11.2 (CMD), J12.3 (CMD), U3.74 (IO_L74N_DOUT_BUSY_1)
/SD_SCK: J11.5 (CLK), J12.5 (CLK), U3.75 (IO_L74P_AWAKE_1)
/SD_WP: J11.11 (WRITE_PROTECT), R18.1
/STDN: R59.1, U3.66 (IO_L2N_CMPMOSI_2), U7.1 (STDN)
/STDNB: R60.1, U3.67 (IO_L2P_CMPCLK_2)
/TAPE_IN: J10.2, J13.5, R66.1, R69.1
/TAPE_OUT: C14.1, J10.3
/TCK: J15.6, U3.109 (TCK)
/TDI: J15.10, U3.110 (TDI)
/TDO: J15.8, U3.106 (TDO)
/TMS: J15.4, U3.107 (TMS)
/VRTC: C57.2, D7.3, R86.1, U12.8 (VDD)
/VS: J7.14, R41.2
/VSYNC: R41.1, U3.85 (IO_L43P_GCLK5_1), U7.15 (VSYNC)
/XA0: U2.3 (A0), U3.141 (IO_L2N_0)
/XA1: U2.4 (A1), U3.139 (IO_L3N_0)
/XA2: U2.5 (A2), U3.137 (IO_L4N_0)
/XA3: U2.6 (A3), U3.134 (IO_L34P_GCLK19_0)
/XA4: U2.7 (A4), U3.133 (IO_L34N_GCLK18_0)
/XA5: U2.16 (A5), U3.120 (IO_L62N_VREF_0)
/XA6: U2.17 (A6), U3.118 (IO_L63N_SCP6_0)
/XA7: U2.18 (A7), U3.116 (IO_L64N_SCP4_0)
/XA8: U2.19 (A8), U3.114 (IO_L65N_SCP2_0)
/XA9: U2.20 (A9), U3.112 (IO_L66P_SCP1_0)
/XA10: U2.26 (A10), U3.104 (IO_L1N_VREF_1)
/XA11: U2.27 (A11), U3.102 (IO_L32P_1)
/XA12: U2.28 (A12), U3.101 (IO_L32N_1)
/XA13: U2.29 (A13), U3.100 (IO_L33P_1)
/XA14: U2.30 (A14), U3.111 (IO_L66N_SCP0_0)
/XA15: U2.38 (A15), U3.131 (IO_L35N_GCLK16_0)
/XA16: U2.39 (A16), U3.138 (IO_L4P_0)
/XA17: U2.40 (A17), U3.140 (IO_L3P_0)
/XA18: U2.41 (A18), U3.142 (IO_L2P_0)
/XA19: U2.25 (A19), U3.105 (IO_L1P_1)
/XA20: U2.42 (A20), U3.143 (IO_L1N_VREF_0)
/XD0: U2.9 (I/O0), U3.132 (IO_L35P_GCLK17_0)
/XD1: U2.10 (I/O1), U3.127 (IO_L36P_GCLK15_0)
/XD2: U2.13 (I/O2), U3.124 (IO_L37P_GCLK13_0)
/XD3: U2.14 (I/O3), U3.123 (IO_L37N_GCLK12_0)
/XD4: U2.31 (I/O4), U3.115 (IO_L65P_SCP3_0)
/XD5: U2.32 (I/O5), U3.117 (IO_L64P_SCP5_0)
/XD6: U2.35 (I/O6), U3.119 (IO_L63P_SCP7_0)
/XD7: U2.36 (I/O7), U3.126 (IO_L36N_GCLK14_0)
/~FLASH_CS0: JP2.1 (A), R44.2, U4.1 (~CS)
/~FLASH_CS1: JP2.3 (B), R45.2, U5.1 (~CS)
/~FLASH_CS: JP2.2 (C), U3.38 (IO_L65N_CSO_B_2)
/~FLASH_HOLD: U3.61 (IO_L12N_D2_MISO3_2), U4.7 (~HOLD), U5.7 (~HOLD)
/~FLASH_WP: U3.62 (IO_L12P_D1_MISO2_2), U4.3 (~WP), U5.3 (~WP)
/~NMI: R2.2, R19.1, SW2.1
/~OE: R13.1, U2.8 (~CE), U2.37 (~OE), U3.144 (IO_L1P_HSWAPEN_0)
/~RESET: C1.2, D8.2 (A), R1.2, SW1.1, U1.1 (~RST), U3.37 (PROGRAM_B_2), U6.38 (~RST/~PD)
/~SD_CD: J11.10 (CARD_DETECT), J12.9 (DET_B), R38.2
/~SD_CS: J11.1 (CD/DAT3), J12.2 (DAT3/CD), U3.59 (IO_L13N_D10_2)
/~SERVICE: R3.2, R43.1, SW3.1
/~WR: U2.15 (~WE), U3.121 (IO_L62P_0)
GND: BT1.2 (-), C1.1, C3.1, C4.1, C8.1, C9.1, C10.1, C11.1, C13.2, C16.2, C17.1, C20.2, C21.2, C22.1, C23.2, C24.1, C25.2, C26.2, C27.1, C28.1, C29.1, C30.1, C31.1, C32.1, C33.1, C34.1, C35.1, C36.2, C37.2, C38.1, C39.1, C40.1, C41.1, C42.1, C43.1, C44.1, C45.1, C46.1, C47.1, C48.1, C49.1, C50.2, C51.1, C52.1, C54.2, C56.1, C57.1, C59.1, C60.1, C61.1, C62.1, C63.1, C64.1, C65.1, C66.1, C67.1, C68.1, C69.2, C71.1, D4.1 (K), D5.1 (K), D6.2 (A), J1.0, J1.3, J2.0, J2.3, J4.0 (PAD), J4.8, J5.8, J5.10, J6.8, J6.10, J7.0, J7.5, J7.6, J7.7, J7.8, J7.10, J8.0 (PAD), J8.8, J10.1, J11.3 (VSS), J11.6 (VSS), J11.12 (SHELL1), J11.13 (SHELL2), J12.6 (VSS), J12.10 (DET_A), J12.11 (SHIELD), J13.4, J15.1, J15.3, J15.5, J15.7, J15.9, J15.11, J15.13, J16.A1 (GND), J16.A12 (GND), J16.B1 (GND), J16.B12 (GND), J16.S1 (SHIELD), JP1.1 (A), JP4.2, Q5.3 (C), Q7.2 (E), R13.2, R14.2, R16.2, R56.2, R57.2, R58.2, R69.2, R74.1, R75.1, R77.1, R78.1, R79.1, R83.2, SW1.2, SW2.2, SW3.2, U1.15 (GND), U2.12 (GND), U2.34 (GND), U3.3 (GND), U3.13 (GND), U3.25 (GND), U3.49 (GND), U3.54 (GND), U3.60 (IO_L13P_M1_2), U3.68 (GND), U3.73 (SUSPEND), U3.77 (GND), U3.91 (GND), U3.96 (GND), U3.108 (GND), U3.113 (GND), U3.130 (GND), U3.136 (GND), U4.4 (GND), U5.4 (GND), U6.4 (AGND), U6.7 (MICIN), U6.9 (GND), U6.10 (A0), U6.13 (GND), U6.14 (~CS), U6.15 (~RD), U6.18 (GND), U6.25 (GND), U6.36 (GND), U6.45 (GND), U6.48 (GND), U6.49 (GND), U7.2 (AGND), U7.12 (SELECT), U7.13 (DGND), U8.1 (GND), U9.1 (GND), U10.4 (V-), U11.8 (GND), U11.15 (E), U12.4 (VSS), U13.2 (I0a), U13.3 (I1a), U13.5 (I0b), U13.6 (I1b), U13.8 (GND), U13.15 (E), U14.1 (GND), U15.2 (GND), U16.1 (GND), U17.2 (GND), X1.2 (GND), Y1.2, Y1.4, Y4.3
unnamed: C2.1, C21.1, R72.2
unnamed: C2.2, R20.1
unnamed: C5.2, R46.2, R47.2, R48.2, R56.1
unnamed: C6.2, R49.2, R50.2, R51.2, R57.1
unnamed: C7.2, R52.2, R54.2, R55.2, R58.1
unnamed: C12.2, R53.2
unnamed: C14.2, R61.2
unnamed: C15.2, R66.2
unnamed: C18.1, R76.1, U10.1
unnamed: C18.2, R23.1, R75.2
unnamed: C19.1, R80.1, U10.7
unnamed: C19.2, R37.1, R79.2
unnamed: C20.1, C58.1, R73.2
unnamed: C53.2, R70.1
unnamed: C55.2, R71.1
unnamed: C58.2, R21.1
unnamed: D1.1 (K), R14.1
unnamed: D2.1 (K), R15.1
unnamed: D3.1 (K), R16.1
unnamed: C69.1, D4.2 (A), R59.2, Y2.2
unnamed: D5.2 (A), R60.2, Y3.2
unnamed: C15.1, C16.1, D6.1 (K), R67.1
unnamed: J3.1, SW5.1 (A)
unnamed: J3.2, SW5.2 (B)
unnamed: J14.R2, JP4.4
unnamed: J16.A5 (CC1), R77.2
unnamed: J16.B5 (CC2), R78.2
unnamed: JP1.2 (B), U1.18 (GPIO0)
unnamed: J7.9, JP3.1 (A)
unnamed: J14.S, JP4.1 (A)
unnamed: J1.5, Q1.3 (D), R6.1
unnamed: J1.1, Q2.3 (D), R7.1
unnamed: J2.5, Q3.3 (D), R11.1
unnamed: J2.1, Q4.3 (D), R12.1
unnamed: Q5.2 (E), R15.2
unnamed: Q7.1 (B), R63.1, R67.2
unnamed: R72.1, U15.4
unnamed: R73.1, U15.6
unnamed: J16.A4 (VBUS), J16.A9 (VBUS), J16.B4 (VBUS), J16.B9 (VBUS), SW4.1
unnamed: R84.1, U1.17 (GPIO2)
unnamed: R83.1, U1.16 (GPIO15)
unnamed: R43.2, U3.56 (IO_L30P_GCLK1_D13_2)
unnamed: R18.2, U3.14 (IO_L44N_GCLK20_3)
unnamed: R19.2, U3.15 (IO_L44P_GCLK21_3)
unnamed: R17.2, U3.12 (IO_L49P_3)
unnamed: R38.1, U3.44 (IO_L62P_D5_2)
unnamed: R32.2, U3.39 (IO_L65P_INIT_B_2)
unnamed: C8.2, C9.2, U6.34 (OUTVC12)
unnamed: C3.2, C4.2, U6.5 (VCM)
unnamed: C11.2, U6.39 (X1), Y1.3
unnamed: C10.2, U6.40 (X2), Y1.1
unnamed: C7.1, U7.8 (BIN)
unnamed: C12.1, U7.10 (COMP)
unnamed: C13.1, U7.3 (FIN), Y2.1, Y3.1
unnamed: C6.1, U7.7 (GIN)
unnamed: C5.1, U7.6 (RIN)
unnamed: C51.2, R8.1, R74.2, U10.3 (+), U10.5 (+)
unnamed: R21.2, R71.2, R76.2, U10.2 (-)
unnamed: R20.2, R70.2, R80.2, U10.6 (-)
unnamed: C50.1, U12.1 (OSCI), Y4.1
unnamed: U12.2 (OSCO), Y4.2
unnamed: R85.1, U12.3 (~INT)
unnamed: C71.2, U17.4 (BP)

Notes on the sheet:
220 Ohm resistors are used to prevent I/O pins damage as on original ZXUNO these pins may be used for other purposes
Reset
Keyboard and mouse
Install C69 if you are experiencing troubles with NTSC colors
JTAG
For PCF8563: install D7, do not install R85 and R86 For DS1307/M41T56: install R85 and R86, do not install D7 PCF8563 recommended
Buttons
LEDs
MIDI
Jumpers 1-2, 3-4, 5-6 1-3, 2-4, 5-6 1-2, 3-5, 4-6
Install U16 or U17+C71
SD card
VGA
2nd joy yes no no
Clock
Tape input/output
NOTE: >6 buttons require software support, which is missing for now
NOTE2: previous PCB revision used VGA2M-like connection of 2nd joystick. This revision uses officially supported joysplitter-compatible connection
SRAM memory
AV out
Buttons 6 7 12
Possible opamp replacements: - AD8606ARZ - OPA2348AIDR - MCP6022T-I/SN - MCP6002T-I/SN - TP8606ARZ - TP8542ARZ
Joysticks
PAL/NTSC encoder
RTC
Alternative microSD slot
Joystick type Atari/Sega Atari Sega
Power
WiFi
FPGA
MH-M18 Bluetooth module header
SPI flash

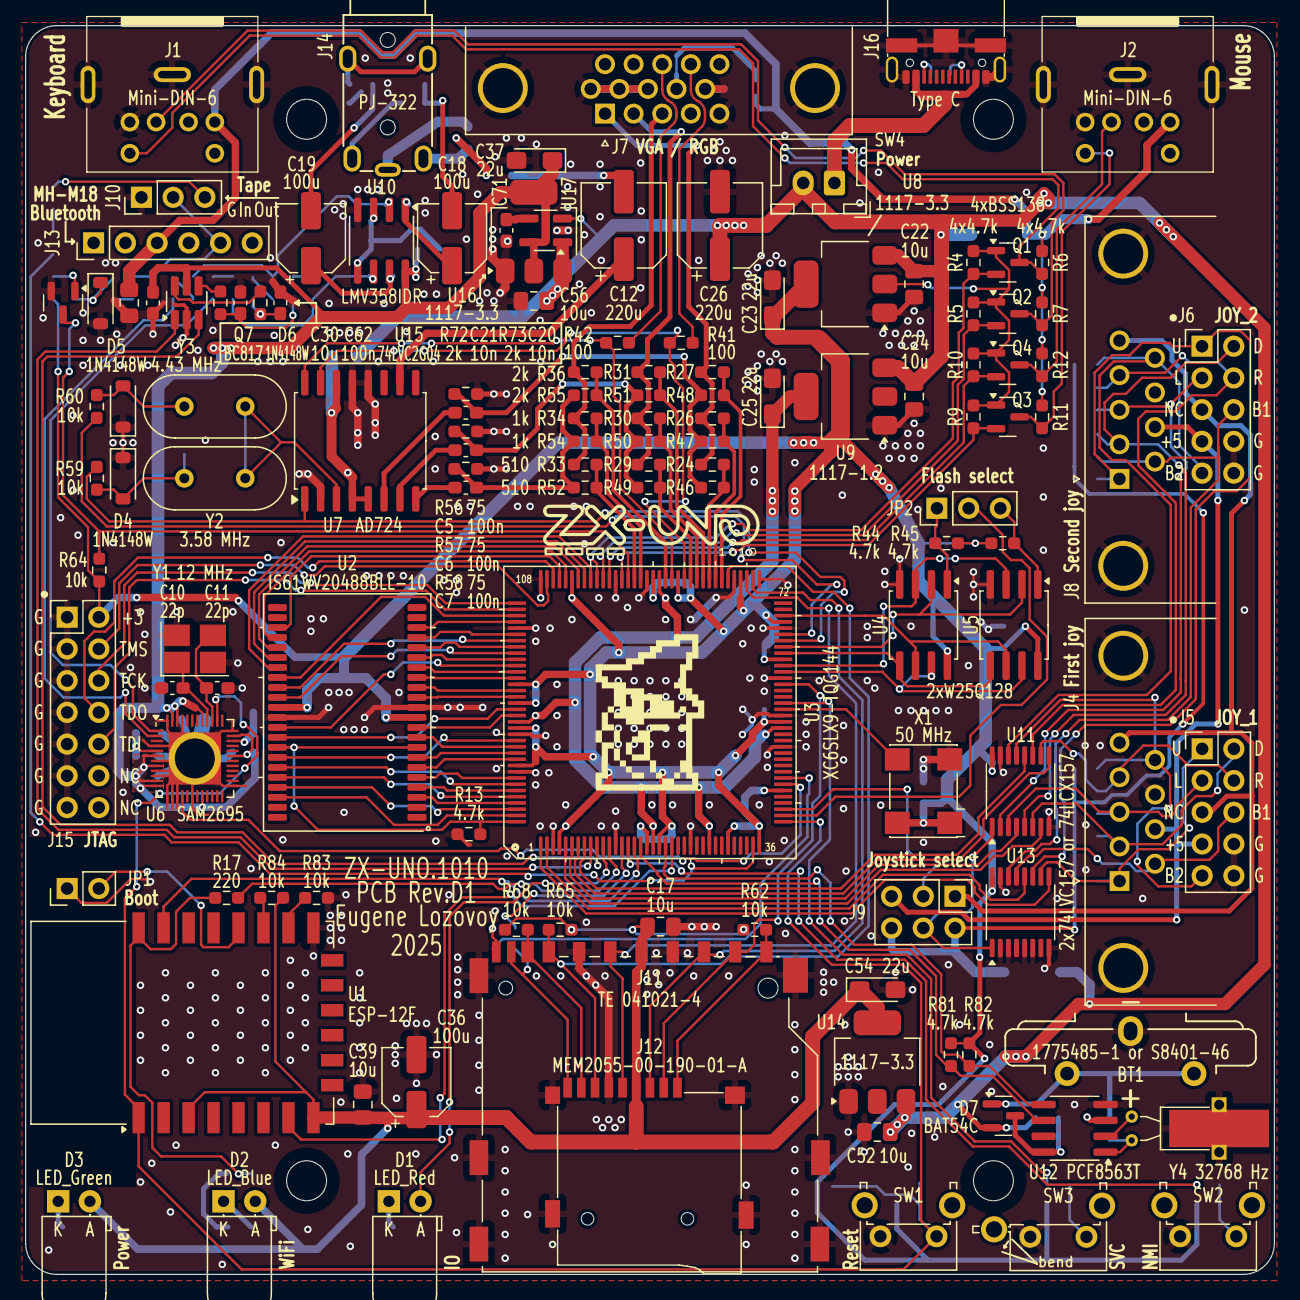
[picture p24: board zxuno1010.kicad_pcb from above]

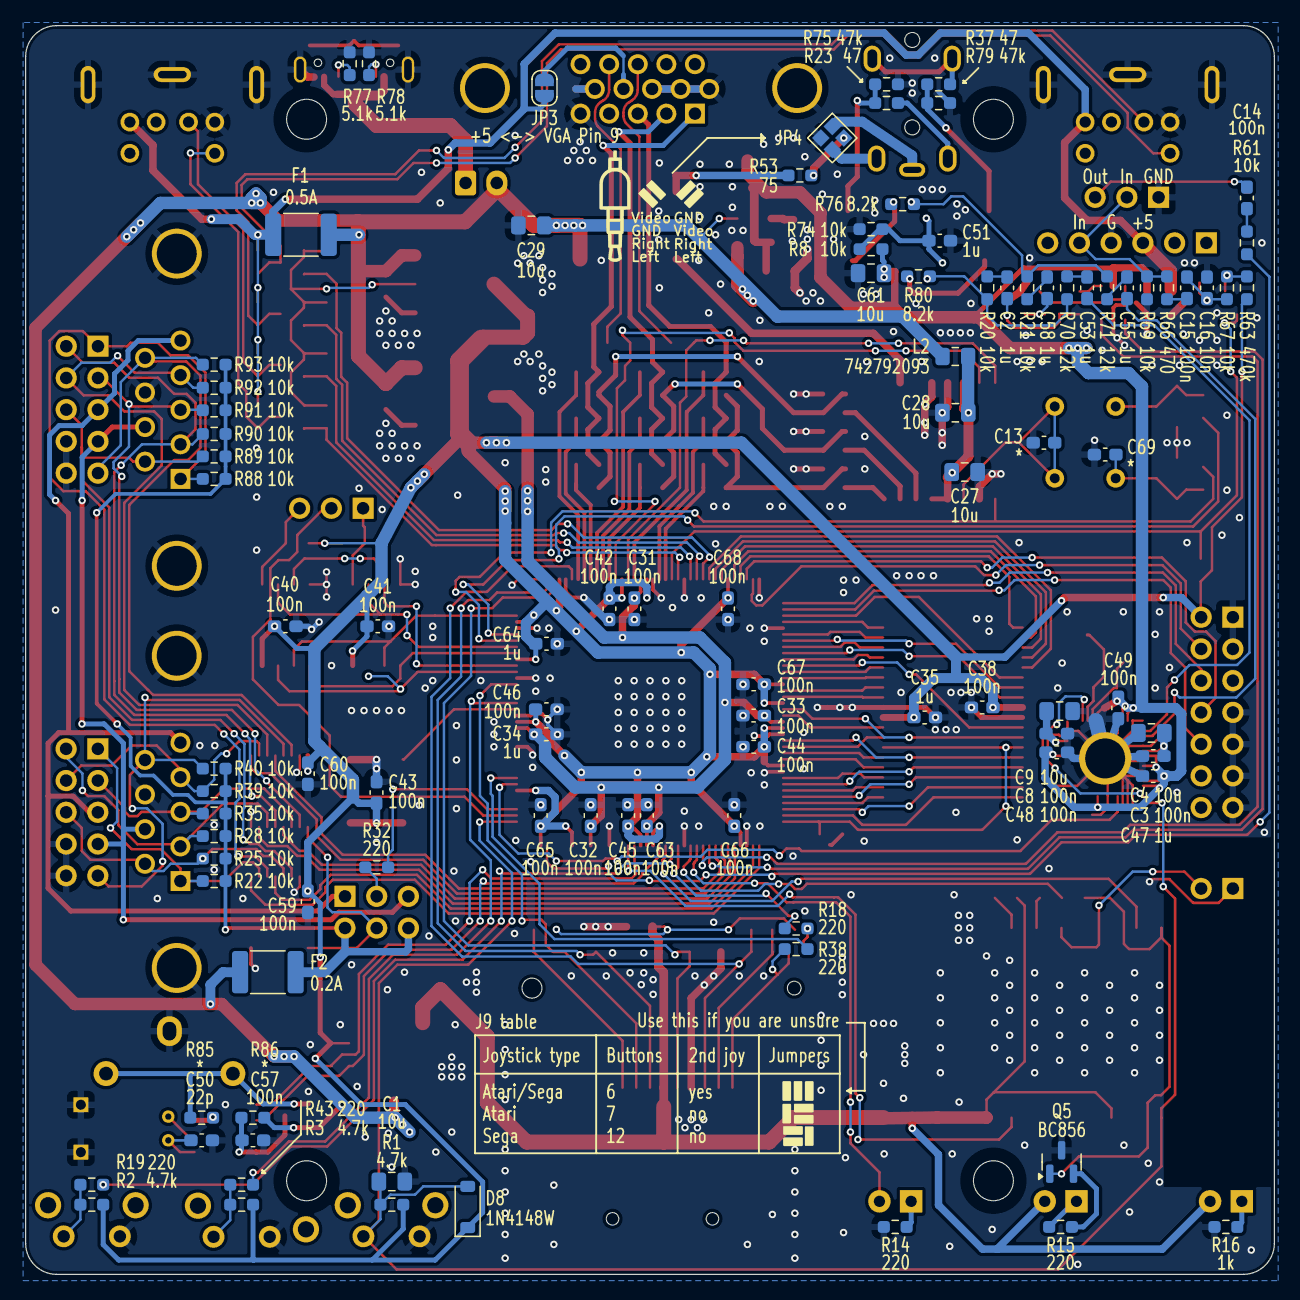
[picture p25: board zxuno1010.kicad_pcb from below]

Board: 2 copper layers, 100.0 x 100.0 mm, 232 parts (97 on the bottom side), 189 nets.

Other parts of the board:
LOGO1: graphic; zxuno_17x4.4
LOGO2: graphic; black-mage-12.5x8.6

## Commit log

2021-09-05 update pcb rev.A
    [zxuno1010.kicad_pcb, zxuno1010.kicad_sch]
2021-11-12 add pcb covers rev.A
    [zxuno1010_covers.kicad_pcb, zxuno1010_covers.kicad_sch]
2021-11-17 update pcb covers rev.A
    [zxuno1010_covers.kicad_pcb]
2021-11-17 update 3d render for pcb rev.A
2021-12-27 add pcb_covers rev.A1
    [zxuno1010_covers.kicad_pcb, zxuno1010_covers.kicad_sch]
2021-12-27 add pcb rev.A1
    [zxuno1010.kicad_pcb, zxuno1010.kicad_sch]
2021-12-27 add pcb rev.A1 gerber, pdf, etc...
2022-05-26 update covers gerbers: fix "Lack of the Bottom Soldermask layer" for pcbway
    [zxuno1010_covers.kicad_pcb, zxuno1010_covers.kicad_sch]
2025-04-19 add pcb rev.B
    [zxuno1010.kicad_pcb, zxuno1010.kicad_sch, zxuno1010_covers.kicad_pcb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]
2025-04-19 add pcb rev.C
    [zxuno1010.kicad_pcb, zxuno1010.kicad_sch]
2025-04-19 add pcb rev.D
    [zxuno1010.kicad_pcb, zxuno1010.kicad_sch, zxuno1010_covers.kicad_pcb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]
2025-04-19 add pcb rev D1 + release
    [zxuno1010.kicad_pcb, zxuno1010.kicad_sch, zxuno1010_covers.kicad_pcb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]
